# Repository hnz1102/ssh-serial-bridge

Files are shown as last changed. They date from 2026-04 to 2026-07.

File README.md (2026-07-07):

<div align="center">
  <h1><code>SSH Serial Bridge</code></h1>
  <p>
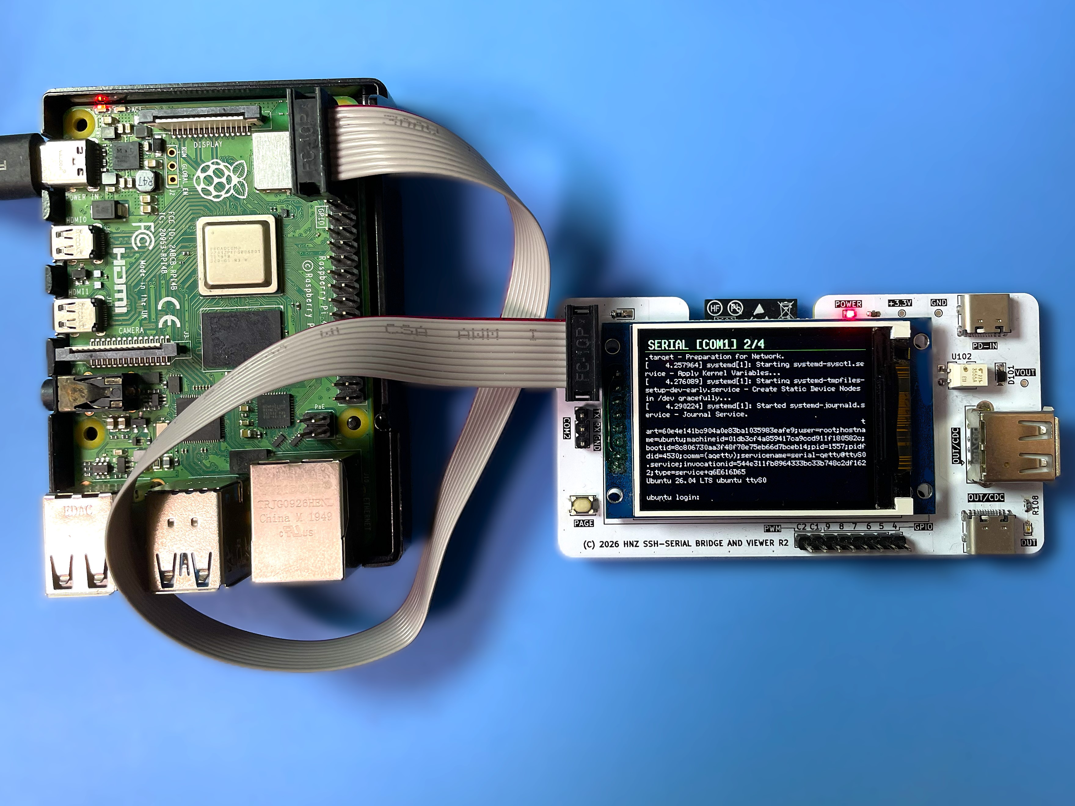
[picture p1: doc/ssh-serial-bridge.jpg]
    
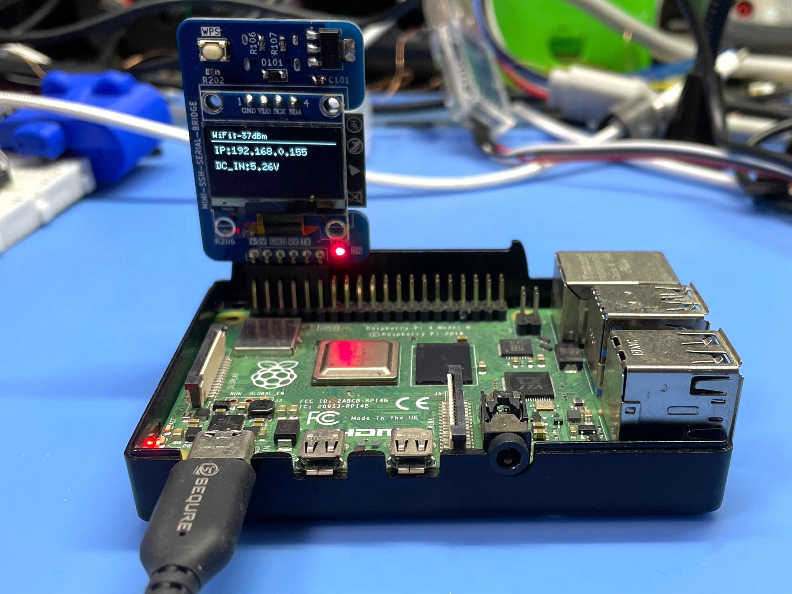
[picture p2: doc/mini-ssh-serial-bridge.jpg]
    
  </p>
</div>

# ssh-serial-bridge - SSH-to-Serial Bridge for Raspberry Pi, USB CDC and UART

Firmware for the ESP32-S3 that bridges an SSH connection (over Wi-Fi) to UART
and USB CDC serial ports.  Written in Rust (esp-idf-hal / esp-idf-svc) with a
C component (wolfSSH) for the SSH server.

## Features

| Feature | Description |
|---|---|
| SSH server | Port 22, username/password authentication via wolfSSH, multiple concurrent sessions (including shared sessions on the same serial port) |
| Serial ports | COM1 / COM2 (UART) and USB CDC (USB Host) — up to 4 ports (`usb0`–`usb3`) |
| Web UI | Browser-based configuration, terminal, and GPIO control |
| WebSocket terminal | Built-in xterm.js; access serial data from the browser at `/terminal` |
| WPS support | Wi-Fi Protected Setup (PBC mode) — configure Wi-Fi via button or Web UI |
| GPIO / PWM | Digital output (ON/OFF) on GPIO 4–9, 12 ; PWM output on GPIO 10–11 |
| SPI display | Optional ST7789V (320×240) display showing incoming serial data |
| UDP Syslog | RFC 5424 remote logging over UDP |
| NTP | Time synchronisation on boot; up to 4 servers configurable via Web UI |
| NVS settings | Persistent configuration stored in NVS; editable via Web UI at runtime |

---

## Architecture

```
SSH client ──[TCP:22]──► ssh_bridge.c (wolfSSH)
                               │
        per-session ring buffers (PSRAM)
                               │
Rust usb_host.rs ◄─────────────┘
 ├── COM1 (UART1)
 ├── COM2 (UART2)
 └── USB CDC (USB Host: PL2303 / FTDI / etc.)

Browser ──[HTTP/WS]──► httpserver.rs
 ├── /terminal  (xterm.js + WebSocket /ws/serial)
 ├── /          (configuration page)
 └── /gpio      (GPIO/PWM control page)
```

---

## Directory Layout

```
ssh-serial-bridge/
├── src/
│   ├── main.rs           # Entry point, peripheral initialisation
│   ├── usb_host.rs       # USB Host (PL2303 etc.) + UART + SSH bridge control
│   ├── httpserver.rs     # HTTP/WebSocket server, NVS config management
│   ├── wifi.rs           # Wi-Fi STA connection (DHCP / static IP)
│   ├── syslogger.rs      # UDP Syslog logger (RFC 5424)
│   ├── serial_display.rs # ST7789V SPI display rendering
│   ├── gpio_ctrl.rs      # Shared GPIO / PWM state
│   ├── btn_ctrl.rs       # GPIO0 button (short press: page cycle; long press: factory reset)
│   └── boot_log.rs       # NVS boot counter and rolling reset-reason log (last 10 entries)
├── components/
│   ├── ssh_bridge/       # SSH server C component (wolfSSH wrapper)
│   ├── wolfssh/          # wolfSSH (github.com/wolfSSL/wolfssh, commit 157cb01f)
│   └── wolfssl/          # wolfSSL/wolfCrypt (github.com/wolfSSL/wolfssl, commit b7e7e755)
├── static/               # Embedded static files (xterm.js / css / fit addon)
├── cfg.toml              # Build-time default configuration (gitignored — contains credentials)
├── cfg.toml.<board>      # Board-specific templates (e.g. ssh-bridge-board / xiao-esp32s3)
├── sdkconfig.defaults    # ESP-IDF build settings
├── partitions.csv        # Flash partition table
├── build-flash-images.sh # Build merged flash + app-only OTA images per board
├── setup_components.sh   # Initial setup script for components/
└── setup_env.sh          # One-shot environment setup (Rust, espup, udev)
```

---

## Pin Assignment

### UART Serial

| Port | Signal | Default GPIO | XIAO-ESP32S3 |
|---|---|---|---|
| COM1 | TX | 17 | 43 |
| COM1 | RX | 18 | 44 |
| COM2 | TX | 19 (41) | — |
| COM2 | RX | 20 (42) | — |

### GPIO / PWM Output

| GPIO | Function |
|---|---|
| 4–9, 12 | Digital output ON/OFF |
| 10–11 | PWM output (LEDC, 1 kHz, 14-bit) |

### SPI Display (ST7789V)

| Signal | GPIO |
|---|---|
| SCLK | 48 |
| MOSI | 45 |
| CS | 40 |
| DC | 39 |
| RST | 38 |

### Button

| GPIO | Function |
|---|---|
| 0 (BOOT) | Short press (<3 s): Cycle display page / Medium press (3–10 s): Toggle DC OUT (GPIO12) / Long press (≥10 s): NVS factory reset |
**Factory Reset Display Indicators:**
- **6–10 seconds** (button held): Display shows "FACTORY RESET" with countdown "Resetting to defaults in X seconds..."
- **10 seconds** (trigger): Display shows "FACTORY RESET" / "Erasing NVS... Please wait..." and device reboots
---

## Configuration

### Board-specific cfg.toml (build-time defaults)

Before building, choose a board config and copy it to `cfg.toml`.

- `ssh-bridge-board`: Board with a 2.0-inch TFT display for serial data output
- `mini-ssh-bridge-board`: Small-display board using SSD1306
- `xiao-esp32s3`: XIAO ESP32S3 board

```bash
# 2.0-inch TFT display board
cp cfg.toml.ssh-bridge-board cfg.toml

# SSD1306 mini display board
cp cfg.toml.mini-ssh-bridge-board cfg.toml

# XIAO ESP32S3 board
cp cfg.toml.xiao-esp32s3 cfg.toml
```

After copying, edit `cfg.toml` for your environment (Wi-Fi credentials, IP, etc.) if needed.

```toml
[ssh-serial-bridge]
wifi_ssid      = "your-ssid"
wifi_psk       = "your-password"
ip_mode        = "dhcp"           # "dhcp" or "static"
ip_address     = "192.168.2.200"
subnet_mask    = "255.255.255.0"
gateway        = "192.168.2.1"
dns            = "1.1.1.1"

syslog_server    = "192.168.2.140:514"
syslog_enable    = "false"
syslog_host_name = "esp32s3"
syslog_app_name  = "ssh-bridge"

ssh_user     = "admin"
ssh_password = "sshpass"

com1_tx_pin = "17"    # XIAO-ESP32S3: 43
com1_rx_pin = "18"    # XIAO-ESP32S3: 44
com1_baud   = "115200"
com2_tx_pin = "41"
com2_rx_pin = "42"
com2_baud   = "115200"

cdc_enable = "false"
cdc_baud   = "115200"

# CDC retry settings (for slow-initializing devices like Raspberry Pi USB Gadget)
cdc_retry_enable   = "true"    # Automatically retry CDC-ACM init until device is ready
cdc_retry_interval = "5"       # Seconds between retries (recommended: 5)

display_enable = "false"
display_port   = "com1"    # "com1" / "com2" / "usb0" / "usb1" / "usb2" / "usb3"

pwm_enable = "true"

# NTP servers (up to 4, in priority order)
ntp_server1 = "time.aws.com"
ntp_server2 = "time.google.com"
ntp_server3 = "time.cloudflare.com"
ntp_server4 = "ntp.nict.jp"

adc_conversion_factor = "74.47"　＃Factor to convert ADC reading to voltage (depends on voltage divider and reference voltage)
```

Values in `cfg.toml` are compiled into the firmware as defaults.  
After boot they can be overridden via the Web UI or direct NVS writes; NVS values take priority.

---

## Wi-Fi Setup with WPS

**WPS (Wi-Fi Protected Setup)** allows you to connect to a Wi-Fi network without manually entering the SSID and password. This device supports **WPS Push Button Configuration (PBC)** mode.

### Method 1: Using cfg.toml and Factory Reset (Recommended for initial setup)

If you don't have Wi-Fi credentials yet or want to reconfigure via WPS without Web UI access:

1. **Edit `cfg.toml` before building** (or rebuild the firmware):
   ```toml
   wifi_ssid      = ""           # Set to empty string
   wps_enable     = "true"       # Enable WPS mode on boot
   ```

2. **Flash the firmware** to the device

3. On boot, the device will automatically enter WPS mode and wait for you to **press the WPS button on your Wi-Fi router** (timeout: 2 minutes)

4. Upon successful WPS connection, the credentials are saved to NVS and the device reboots

**Alternative: Trigger WPS via Factory Reset**

If the device is already running with Wi-Fi configured but you want to switch to WPS:

1. **Edit `cfg.toml`** to set `wps_enable = "true"` and `wifi_ssid = ""`
2. **Rebuild and flash** the firmware
3. **Perform a Factory Reset**: Press and hold the BOOT button (GPIO 0) for **≥10 seconds**
4. The device will erase NVS, restore `cfg.toml` defaults, and reboot into WPS mode
5. **Press the WPS button on your Wi-Fi router** within 2 minutes

> **Note**: Web UI is not accessible until Wi-Fi is connected, so this method is essential for initial setup or when you lose Wi-Fi access.

---

### Method 2: Using the Web UI (when already connected to Wi-Fi)

1. Navigate to the configuration page at `http://<device_ip>/`
2. Find the **WPS** section
3. Click the **"Start WPS"** button
4. **Press the WPS button on your Wi-Fi router** within 2 minutes
5. The device will automatically receive and save the Wi-Fi credentials and reboot

### WPS Status Indicators

When WPS is active:
- **Display (if enabled)**: Shows "WPS MODE" with countdown timer (120 seconds)
  - "Press WPS button on your router within 120 seconds"
  - Countdown updates every 10 seconds
  - On success: "WPS SUCCESS" → "Connecting to {SSID}" → "CONNECTED"
- **Syslog (if enabled)**: Logs WPS start, success, or failure events
- **Web UI**: Shows WPS status during the connection process

### WPS Fallback

If WPS fails or times out, the device will revert to the previously configured Wi-Fi credentials (from `cfg.toml` or NVS).

### Notes

- WPS PBC mode is the only supported WPS method (PIN mode is not supported)
- After successful WPS configuration, the new credentials are saved to NVS and persist across reboots
- You can still manually configure Wi-Fi credentials via `cfg.toml` or the Web UI if WPS is not available on your router

---

## Environment Setup

Run `setup_env.sh` **once** on a fresh Ubuntu / Debian machine (or WSL2) before
building.  The script performs all steps below automatically.

```bash
bash setup_env.sh
```

After the script finishes, open a new terminal (or reload your shell config) so
the environment variables take effect:

```bash
source "$HOME/.cargo/env"
source ~/export-esp.sh
```

### What the script does

| Step | Action |
|---|---|
| 1 | Install system packages via `apt` |
| 2 | Install Rust toolchain via `rustup` (skipped if already present) |
| 3 | Install `ldproxy`, `espup`, `cargo-espflash` via Cargo |
| 4 | Install & update the ESP32-S3 Xtensa toolchain via `espup` |
| 5 | Source `~/export-esp.sh` (generated by `espup`) |
| 6 | Add udev rule for ESP32 USB device (`303a:1001`) and reload rules |

> If you prefer to run the steps manually, expand each step below.

<details>
<summary>Manual setup steps</summary>

```bash
# 1. System packages
sudo apt update && sudo apt -y install \
    git python3 python3-pip gcc build-essential curl \
    pkg-config libudev-dev libtinfo5 clang libclang-dev \
    llvm-dev udev libssl-dev python3.10-venv

# 2. Rust
curl --proto '=https' --tlsv1.2 -sSf https://sh.rustup.rs | sh
# Select option 1 (default install), then:
source "$HOME/.cargo/env"

# 3. Cargo tools
cargo install ldproxy
cargo install espup
cargo install cargo-espflash

# 4. ESP32-S3 toolchain
espup install
espup update

# 5. Activate ESP environment (add to ~/.bashrc / ~/.zshrc for persistence)
. ~/export-esp.sh

# 6. udev rules
sudo sh -c 'echo "SUBSYSTEMS==\"usb\", ATTRS{idVendor}==\"303a\", ATTRS{idProduct}==\"1001\", MODE=\"0666\"" > /etc/udev/rules.d/99-esp32.rules'
sudo udevadm control --reload-rules
sudo udevadm trigger
```

</details>

---

## Build and Flash

### Prerequisites

- Rust toolchain: `esp` channel (selected automatically via `rust-toolchain.toml`)
- [espup](https://github.com/esp-rs/espup) — ESP32-S3 Xtensa toolchain
- [espflash](https://github.com/esp-rs/espflash)

### Initial component setup

Run once after cloning, or after a clean wipe of `components/`:

```bash
cd esp32-s3/ssh-serial-bridge
bash setup_components.sh
```

This clones wolfssh and wolfssl at the verified commits and places the
ESP-IDF-specific `CMakeLists.txt` and `include/user_settings.h` on top.

### Build

```bash
cargo build --release
```

### Flash and monitor

```bash
espflash flash --release --monitor
```

### Creating a complete flash binary image

To create a single binary file that includes all partitions (bootloader,
partition table, data partitions, and the currently built app image) for
distribution or web-based flashing:

```bash
cargo espflash save-image --release --merge --chip esp32s3 complete_flash.bin
```

This creates a complete 8 MB flash image starting from offset 0x0.

### Creating board images for both USB flashing and OTA

The helper script builds all board configs and produces both image types:

- `flash_images/flash_<board>.bin` (merged full-flash image, write at `0x0`)
- `flash_images/app_<board>.bin` (app-only image for `ssh ... update` OTA)

```bash
bash build-flash-images.sh
```

**Important**: When flashing this image, always write it to **offset 0x0**, not 0x9000. Writing to 0x9000 will result in a boot failure with "invalid header: 0xffffffff" error.

#### Flash the complete binary

```bash
# Using esptool.py
esptool.py --chip esp32s3 --port /dev/ttyUSB0 write_flash 0x0 complete_flash.bin

# Using espflash
espflash write-bin 0x0 complete_flash.bin
```

#### Web-based flashing (no command line required)

You can also flash the binary via a web browser using the ESP Web Flasher:

1. Open [https://thelastoutpostworkshop.github.io/ESPConnect/](https://thelastoutpostworkshop.github.io/ESPConnect/) in Chrome, Edge, or Opera (Web Serial API required)
2. Click **"Connect"** and select your ESP32-S3 device from the serial port list
3. Click **"Choose File"** and select `complete_flash.bin`
4. Set the flash address to **`0x0`** (very important!)
5. Click **"Program"** to start flashing
6. Wait for the process to complete and click **"Reset Device"**

This method is ideal for:
- Users without command-line tools installed
- Quick firmware updates without installing the Rust/ESP toolchain
- Distribution of pre-built binaries

### Flash layout

| Partition | Offset  | Size |
|---|---|---|
| nvs | 0x9000  | 24 KB  |
| otadata | 0xF000  | 8 KB |
| phy_init | 0x11000 | 4 KB |
| ota_0 (app) | 0x20000 | 4032 KB |
| ota_1 (app) | 0x410000 | 4032 KB |

Flash: 8 MB, DIO mode, 40 MHz.

---

## Web UI Endpoints

### Web UI Snapshots

<div align="center">
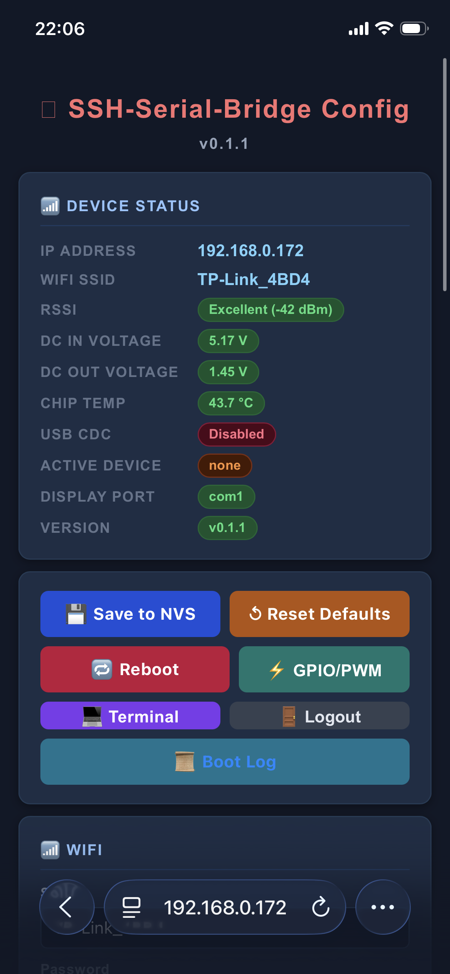
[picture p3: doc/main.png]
Web UI main configuration page
  
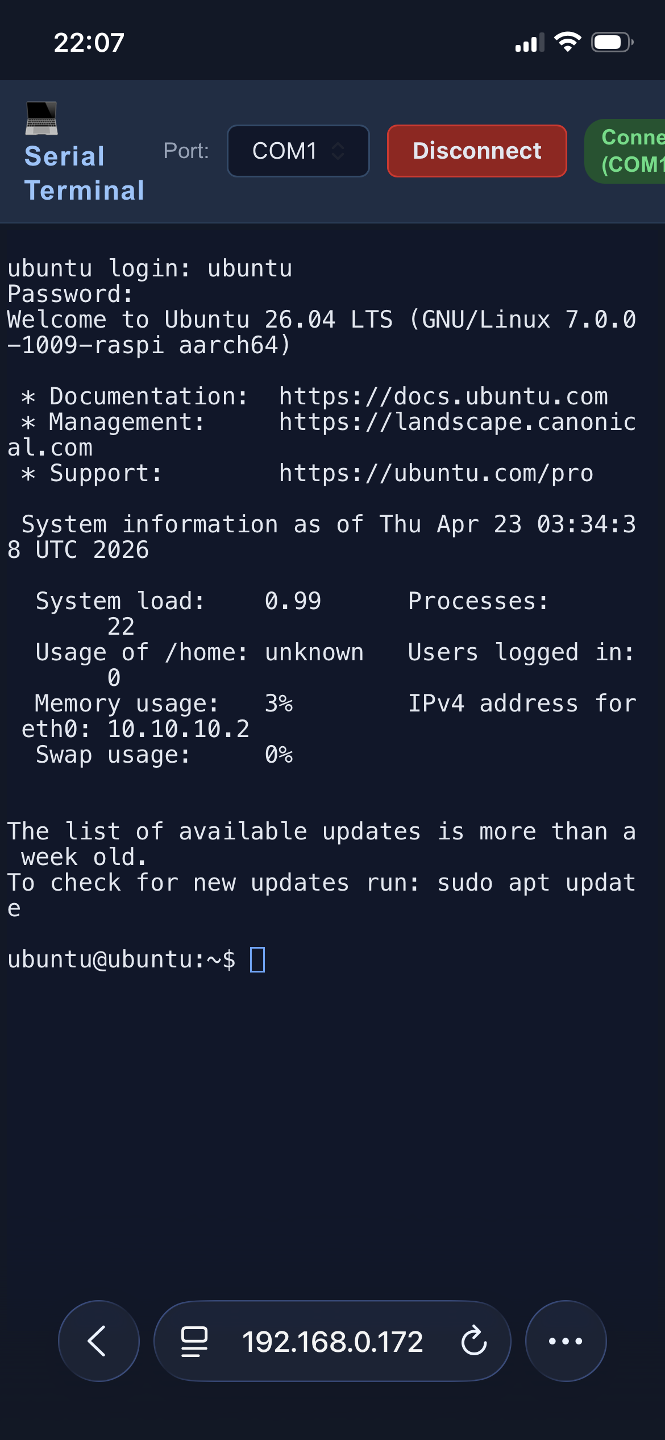
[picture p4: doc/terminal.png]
Web UI terminal page
  
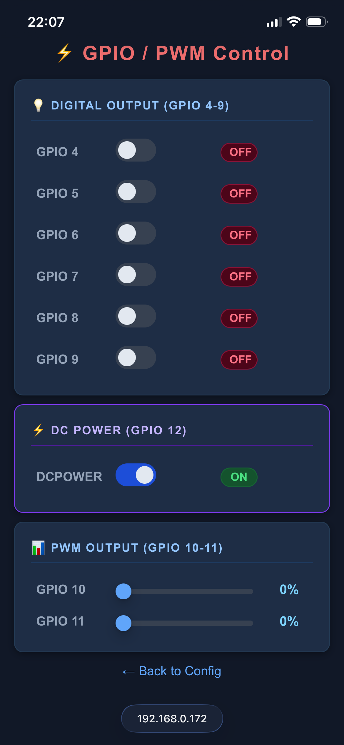
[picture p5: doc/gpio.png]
Web UI GPIO control page
  
</div>

| URL | Method | Description |
|-----|---|---|
| `/login` | GET / POST | Login |
| `/logout` | GET | Logout |
| `/` | GET | Configuration page (auth required) |
| `/gpio` | GET | GPIO / PWM control page (auth required) |
| `/terminal` | GET | WebSocket serial terminal (auth required) |
| `/ws/serial` | WS | Bidirectional serial bridge |
| `/api/config` | POST | Save configuration to NVS |
| `/api/status` | GET | Device / Wi-Fi / USB status (JSON) |
| `/api/reset` | POST | Erase NVS and restore cfg.toml defaults |
| `/api/reboot` | POST | Reboot the device |
| `/api/gpio` | POST | Set one digital output ON/OFF |
| `/api/pwm` | POST | Set PWM duty cycle (0–100 %) |
| `/api/gpio_state` | GET | Current GPIO / PWM state (JSON) |
| `/api/boot_log` | GET | Boot history with reset reasons from NVS (JSON) |

---

## SSH Connection

### Authentication

| Item | Detail |
|---|---|
| Port | 22 (TCP) |
| Auth method | Password only (public-key authentication is not supported) |
| Username | Any string is accepted — only the password is checked |
| Password | Set via `ssh_password` in `cfg.toml` or Web UI (default: `esp32`) |
| Concurrent sessions | Up to 6 total SSH sessions (including command sessions) |
| Per-device console sharing | Up to 4 concurrent console sessions on the same target (`usb0`-`usb3`, `com1`, `com2`) |

> **Security note:** Change the default password before deploying the device
> on a shared network.

---

### Commands

The SSH server dispatches on the command passed after the host.  
If no command is given, a usage summary is printed and the connection closes.

#### 1. Serial console bridge

Connects the SSH session as a transparent terminal to a serial port.

```bash
ssh -tt <user>@<device_ip> console (usb0|usb1|usb2|usb3|com1|com2)
```

| Argument | Description |
|---|---|
| `usb0` | First USB CDC device (plug order; alias: `usb`) |
| `usb1` | Second USB CDC device |
| `usb2` | Third USB CDC device |
| `usb3` | Fourth USB CDC device |
| `com1` | UART1 (pins configured by `com1_tx_pin` / `com1_rx_pin`) |
| `com2` | UART2 (pins configured by `com2_tx_pin` / `com2_rx_pin`) |

- The `-tt` flag forces pseudo-TTY allocation, which is required for correct
  terminal behaviour.
- A welcome banner is printed on connect:
  ```
  Connected to ESP32-S3 SSH-Serial-Bridge v0.1.1 [com1].
  Disconnect: Enter then ~.
  ```
- The same serial target can be shared by multiple SSH clients.  When another
  session is already connected to that target, the banner also shows:
  ```
  Note: N other session(s) are also connected to this device — input/output is shared.
  ```
- Shared-session behaviour on the same target:
  - RX from device is broadcast to all connected SSH sessions on that target.
  - TX from each SSH session is sent to the same physical serial line, so input
    from multiple users can interleave.
- Capacity limits:
  - Max 4 console sessions per target (`com1`, `com2`, `usb0`-`usb3`).
  - Max 6 total SSH sessions across the system.
- If a target already has 4 console sessions, new attempts are rejected with:
  ```
  Error: too many sessions already connected to this device (max 4).
  ```
- Serial data received before the first keystroke from the SSH client is
  discarded to prevent stale output flooding the terminal on login.
- Disconnect with the standard OpenSSH escape sequence: press **Enter**, then
  type **`~.`**

**Examples:**

```bash
# Connect to the first USB CDC device
ssh -tt admin@192.168.2.200 console usb0

# Connect to the second USB CDC device
ssh -tt admin@192.168.2.200 console usb1

# Connect to COM1 (UART1)
ssh -tt admin@192.168.2.200 console com1

# Connect to COM2 (UART2)
ssh -tt admin@192.168.2.200 console com2
```

---

#### 2. GPIO digital output control

Controls GPIO4–GPIO9 output pins (mapped as power outlets 1–6).

```bash
ssh <user>@<device_ip> power <1-6> (on|off)
```

| Argument | Description |
|---|---|
| `1`–`6`  | Outlet number: 1 = GPIO4, 2 = GPIO5, … 6 = GPIO9 |
| `on` | Set output HIGH |
| `off` | Set output LOW  |

**Examples:**

```bash
ssh admin@192.168.2.200 power 1 on    # GPIO4 → HIGH
ssh admin@192.168.2.200 power 3 off   # GPIO6 → LOW
```

---

#### 3. DC Power output control (GPIO12)

Controls the dedicated DC Power output on GPIO12.

```bash
ssh <user>@<device_ip> dcpower (on|off)
```

**Examples:**

```bash
ssh admin@192.168.2.200 dcpower on
ssh admin@192.168.2.200 dcpower off
```

---

#### 4. DC Power power-cycle (GPIO12)

Turns the DC Power output off, waits briefly, then turns it back on — in a single SSH call.

```bash
ssh <user>@<device_ip> powercycle
```

**Example:**

```bash
ssh admin@192.168.2.200 powercycle
```

---

#### 5. PWM duty cycle control

Sets the PWM duty cycle on GPIO10 or GPIO11 (LEDC, 1 kHz, 14-bit).

```bash
ssh <user>@<device_ip> pwm <1|2> <0-100>
```

| Argument | Description |
|---|---|
| `1` | Channel 1 — GPIO10 |
| `2` | Channel 2 — GPIO11 |
| `0`–`100`| Duty cycle in percent |

**Examples:**

```bash
ssh admin@192.168.2.200 pwm 1 50    # GPIO10 → 50 %
ssh admin@192.168.2.200 pwm 2 0     # GPIO11 → off
ssh admin@192.168.2.200 pwm 1 100   # GPIO10 → full on
```

---

#### 6. Reboot the device

Reboots the ESP32-S3 (equivalent to a power-on reset).

```bash
ssh <user>@<device_ip> reboot
```

**Example:**

```bash
ssh admin@192.168.2.200 reboot
```

---

#### 7. OTA firmware update

Streams a new app image over SSH directly into the inactive OTA partition, then
reboots into it. No filesystem, SCP, or SFTP support is required — the exec
channel's stdin is piped straight into flash.

```bash
ssh <user>@<device_ip> update < firmware.bin
```

**Example:**

```bash
cat flash_images/app_ssh-bridge-board.bin | ssh admin@192.168.2.200 update
```

**Important:**

- Use the **app-only** image (`flash_images/app_<board>.bin`, produced by
  `build-flash-images.sh`), **not** the merged full-flash image
  (`flash_images/flash_<board>.bin`). The merged image includes the
  bootloader and partition table baked in at offset 0 and will corrupt the
  OTA partition if written this way.
- The device has two OTA app slots (`ota_0`/`ota_1`). The update is written to
  whichever slot isn't currently running, so the previous firmware is left
  untouched until the new image is fully received and verified.
- **Rollback safety:** the new image boots in a "pending verify" state. Once
  the SSH bridge starts successfully it is marked valid automatically. If the
  new firmware crashes or fails to boot before that point, the bootloader
  automatically reverts to the previous working firmware on the next reset.
- This requires the partition table to include `ota_0`/`ota_1`/`otadata`
  (see `partitions.csv`). Boards flashed with an older single-partition image
  must be reflashed once via USB/serial (`cargo espflash flash` or the merged
  `flash_<board>.bin` image) before OTA updates over SSH will work.

---

### Usage summary (printed on unknown command)

```
ESP32-S3 SSH-Serial-Bridge
Usage:
  ssh -tt admin@host console (usb0|usb1|usb2|usb3|com1|com2)  -- Serial console bridge
  ssh    admin@host power   (1-6) (on|off)    -- GPIO4-9 output control
  ssh    admin@host dcpower (on|off)          -- DC Power output (GPIO12)
  ssh    admin@host powercycle                -- DC Power off->on (GPIO12)
  ssh    admin@host pwm   (1|2) (0-100)       -- PWM GPIO10-11 duty %
  ssh    admin@host reboot                    -- Reboot the ESP32-S3
  ssh    admin@host update < firmware.bin      -- OTA firmware update
```

---

## Supported USB CDC Devices

The USB Host driver auto-detects the connected adapter by VID/PID and applies
the appropriate initialisation sequence.  The baud rate is set by `cdc_baud`
in `cfg.toml` (default: `115200`).

> **Note:** `cdc_enable` must be set to `"true"` in `cfg.toml` (or via Web UI)
> to activate the USB Host driver.  When disabled, `usb0`–`usb3` are
> unavailable as SSH console targets.

### Vendor-class adapters

| Chip | VID | PID(s) | Ports | Notes |
|---|-----|---|---|---|
| **PL2303** | `067B` | `2303`, `23A3`, `2304` | 1 | Prolific Technology |
| **CP210x** | `10C4` | `EA60`, `EA61`, `EA70` | 1 | Silicon Labs |
| **FT232R** | `0403` | `6001` | 1 | FTDI |
| **FT232H** | `0403` | `6014` | 1 | FTDI |
| **FT2232H/D** | `0403` | `6010` | 2 | FTDI — maps to `usb0` / `usb1` |
| **FT4232H** | `0403` | `6011` | 4 | FTDI — maps to `usb0`–`usb3` |

### Linux USB Gadget (Raspberry Pi)

This firmware supports **Raspberry Pi USB Gadget mode** for direct serial access over USB:

| Device | VID | PID | Module | Notes |
|---|-----|-----|---|---|
| **Raspberry Pi (g_cdc)** | `0525` | `a4a7` | `g_cdc` | CDC-ACM composite device (recommended) |

#### Raspberry Pi Configuration

To use your Raspberry Pi as a USB serial gadget with this ESP32-S3 bridge:

1. **Enable USB gadget mode** on your Raspberry Pi:
   ```bash
   # Add to /boot/config.txt (or /boot/firmware/config.txt on Ubuntu)
   dtoverlay=dwc2
   ```

2. **Load the g_cdc module** (recommended over g_serial):
   
   **Method A: Using cmdline.txt (Recommended)**
   ```bash
   # Edit /boot/cmdline.txt (or /boot/firmware/cmdline.txt on Ubuntu)
   # Add modules-load=dwc2,g_cdc to the kernel command line
   # Example:
   console=serial0,115200 ... modules-load=dwc2,g_cdc ...
   ```
   
   **Method B: Using /etc/modules**
   ```bash
   # Add to /etc/modules
   dwc2
   g_cdc
   ```

3. **Enable serial-getty service** (required for the CDC device to respond):
   ```bash
   sudo systemctl enable serial-getty@ttyGS0
   sudo systemctl start serial-getty@ttyGS0
   ```

4. **Reboot your Raspberry Pi**:
   ```bash
   sudo reboot
   ```

5. **Connect the Pi to the ESP32-S3 USB port** using a USB cable

> **Important:** Use `g_cdc` instead of `g_serial`. The `g_serial` module has compatibility issues with the ESP-IDF USB Host stack and may not work reliably. `g_cdc` provides better standards compliance and works seamlessly with this firmware.

After configuration, the Pi will appear as a CDC-ACM device and you can access its serial console via SSH to the ESP32-S3 bridge (target: `usb0`).

### Port mapping

Multi-port FTDI adapters expose multiple ports, mapped to SSH console targets
in channel order:

| SSH target | Description |
|---|---|
| `usb0` | Port 1 — all single-port adapters; FT2232 ch.A; FT4232 ch.A |
| `usb1` | Port 2 — FT2232 ch.B; FT4232 ch.B |
| `usb2` | Port 3 — FT4232 ch.C |
| `usb3` | Port 4 — FT4232 ch.D |

---

## Dependencies

| Component / Library | Version | License | Purpose |
|---|---|---|---|
| **ssh-serial-bridge** (this project) | 0.1.1 | MIT | Firmware (Rust) |
| **ssh_bridge** component | 0.1.1 | MIT | SSH server C wrapper |
| esp-idf-hal | 0.45.2 | MIT / Apache-2.0 | ESP32-S3 hardware abstraction |
| esp-idf-svc | 0.51 | MIT / Apache-2.0 | Wi-Fi, HTTP server, SNTP, etc. |
| **wolfSSH** | commit `157cb01f` | GPLv3 (or commercial) | SSH server protocol |
| **wolfSSL / wolfCrypt** | commit `b7e7e755` | GPLv3 (or commercial) | Cryptography library |
| mipidsi | 0.8.0 | MIT | ST7789V display driver |
| embedded-graphics | 0.8.1 | MIT | Display rendering |
| @xterm/xterm | 6.0.0 (bundled) | MIT | Browser WebSocket terminal |
| @xterm/addon-fit | 0.11.0 (bundled) | MIT | xterm.js terminal fit addon |

> **Note on wolfSSH / wolfSSL licensing:**  
> Both wolfSSH and wolfSSL are dual-licensed under **GPLv3** (open source) or a
> **commercial license** (for use in proprietary products).

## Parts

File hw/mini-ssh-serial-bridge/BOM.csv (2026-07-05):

Reference | Qty | Value | DNP | Exclude from BOM | Exclude from Board | Footprint | digikey
C101,C201,C202 | 3 | 0.1uF |  |  |  | Capacitor_SMD:C_0603_1608Metric | 311-1343-1-ND
C203 | 1 | 10uF |  |  |  | Capacitor_SMD:C_0805_2012Metric | 311-1355-1-ND
D101 | 1 | CUHS20F60 |  |  |  | Diode_SMD:D_PowerDI-123 | 264-CUHS20F60H3FCT-ND
D103 | 1 | LED RED |  |  |  | LED_SMD:LED_0603_1608Metric | 3147-B1931URO-20D000114U1930CT-ND
FB101 | 1 | MH2029-601Y |  |  |  | Inductor_SMD:L_0805_2012Metric | MH2029-601YCT-ND
J101 | 1 | USB4105-GF-A |  |  |  | tbctl:USB_C_5077CR-16-SMC2-BK-TR | 2073-USB4105-GF-ACT-ND
J102 | 1 | Conn_01x06 |  |  |  | Connector_PinHeader_2.54mm:PinHeader_1x06_P2.54mm_Vertical | S5442-ND
R105 | 1 | 330 |  |  |  | Resistor_SMD:R_0603_1608Metric | 13-RC0603JR-13330RLCT-ND
R106,R107 | 2 | 5K1 |  |  |  | Resistor_SMD:R_0603_1608Metric | 311-5.10KHRCT-ND
R201,R202 | 2 | 10K |  |  |  | Resistor_SMD:R_0603_1608Metric | 311-10.0KHRCT-ND
R204 | 1 | 47K 1% |  |  |  | Resistor_SMD:R_0603_1608Metric | 311-47.0KHRCT-ND
R206 | 1 | 4.7K 1% |  |  |  | Resistor_SMD:R_0603_1608Metric | 311-4.70KHRCT-ND
SW304 | 1 | 1 |  |  |  | tbctl:SW_SKRPACE010_4mm_3mm | P12298SCT-ND
U101 | 1 | SSD1306_DISPLAY |  |  |  | tbctl:OLED I2C DISPLAY | https://akizukidenshi.com/catalog/g/g112031/
U103 | 1 | AZ1117-CH3.3TRG1 |  |  |  | Package_TO_SOT_SMD:SOT-223-3_TabPin2 | AZ1117CH-3.3TRG1DICT-ND
U201 | 1 | ESP32-S3-WROOM-1-N16R8 |  |  |  | tbctl:ESP32-S3-WROOM-1_EXP | 1965-ESP32-S3-WROOM-1-N16R8CT-ND

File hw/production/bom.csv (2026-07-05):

Designator | Footprint | Quantity | Value | LCSC Part #
C101, C201, C202 | 0603 | 3 | 0.1uF
C203 | 0805 | 1 | 10uF
D101 | D_PowerDI-123 | 1 | CUHS20F60
D103 | 0603 | 1 | LED RED
D402 | 0603 | 1 | LED BLUE
FB101 | 0805 | 1 | MH2029-601Y
J1 | PinHeader_1x04_P2.54mm_Vertical | 1 | Conn_01x04
J101, J102 | USB_C_5077CR-16-SMC2-BK-TR | 2 | USB4105-GF-A
J104 | PinHeader_2x05_P2.54mm_Vertical | 1 | Conn_02x05_Odd_Even
J105 | USB_A_5075AR-04 | 1 | USB_A
J2 | PinHeader_1x10_P2.54mm_Vertical | 1 | Conn_01x10
R101 | 0603 | 1 | 150
R102, R204 | 0603 | 2 | 47K 1%
R103, R206 | 0603 | 2 | 4.7K 1%
R104, R109 | 0603 | 2 | 75K
R105 | 0603 | 1 | 330
R106, R107 | 0603 | 2 | 5K1
R108 | 0603 | 1 | 1K
R110, R111 | 0603 | 2 | 51K
R201, R202 | 0603 | 2 | 10K
SW304 | SW_SKRPACE010_4mm_3mm | 1 | 1
TP101 | TestPoint_Pad_D1.0mm | 1 | 3V3
TP102 | TestPoint_Pad_D1.0mm | 1 | GND
TP103 | TestPoint_Pad_D1.0mm | 1 | VBUS_OUT
U101 | ST7789V TFT SPI DISPLAY 320x240 GMT020-02-8P | 1 | ST7789V_TFT_DISPLAY_8P
U102 | DIP-4_W7.62mm | 1 | TLP3555A
U103 | SOT-223-3_TabPin2 | 1 | AZ1117-CH3.3TRG1
U201 | ESP32-S3-WROOM-1_EXP | 1 | ESP32-S3-WROOM-1-N16R8

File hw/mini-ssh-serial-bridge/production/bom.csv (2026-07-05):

Designator | Footprint | Quantity | Value | LCSC Part #
C101, C201, C202 | 0603 | 3 | 0.1uF
C203 | 0805 | 1 | 10uF
D101 | D_PowerDI-123 | 1 | CUHS20F60
D103 | 0603 | 1 | LED RED
FB101 | 0805 | 1 | MH2029-601Y
J101 | USB_C_5077CR-16-SMC2-BK-TR | 1 | USB4105-GF-A
J102 | PinHeader_1x06_P2.54mm_Vertical | 1 | Conn_01x06
R105 | 0603 | 1 | 330
R106, R107 | 0603 | 2 | 5K1
R201, R202 | 0603 | 2 | 10K
R204 | 0603 | 1 | 47K 1%
R206 | 0603 | 1 | 4.7K 1%
SW304 | SW_SKRPACE010_4mm_3mm | 1 | 1
U101 | OLED I2C DISPLAY | 1 | SSD1306_DISPLAY
U103 | SOT-223-3_TabPin2 | 1 | AZ1117-CH3.3TRG1
U201 | ESP32-S3-WROOM-1_EXP | 1 | ESP32-S3-WROOM-1-N16R8

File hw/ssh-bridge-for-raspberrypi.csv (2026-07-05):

Reference | Qty | Value | DNP | Exclude from BOM | Exclude from Board | Footprint | digikey
C101,C201,C202 | 3 | 0.1uF |  |  |  | Capacitor_SMD:C_0603_1608Metric | 311-1343-1-ND
C203 | 1 | 10uF |  |  |  | Capacitor_SMD:C_0805_2012Metric | 311-1355-1-ND
D101 | 1 | CUHS20F60 |  |  |  | Diode_SMD:D_PowerDI-123 | 264-CUHS20F60H3FCT-ND
D103 | 1 | LED RED |  |  |  | LED_SMD:LED_0603_1608Metric | 3147-B1931URO-20D000114U1930CT-ND
D402 | 1 | LED BLUE |  |  |  | LED_SMD:LED_0603_1608Metric | 3147-B1931NB--20C007614U1930CT-ND
FB101 | 1 | MH2029-601Y |  |  |  | Inductor_SMD:L_0805_2012Metric | MH2029-601YCT-ND
J1 | 1 | Conn_01x04 |  |  |  | Connector_PinHeader_2.54mm:PinHeader_1x04_P2.54mm_Vertical | 732-5317-ND
J2 | 1 | Conn_01x10 |  |  |  | Connector_PinHeader_2.54mm:PinHeader_1x10_P2.54mm_Vertical | 732-2670-ND
J101,J102 | 2 | USB4105-GF-A |  |  |  | Library:USB_C_5077CR-16-SMC2-BK-TR | 2073-USB4105-GF-ACT-ND
J104 | 1 | Conn_02x05_Odd_Even |  |  |  | Connector_PinHeader_2.54mm:PinHeader_2x05_P2.54mm_Vertical | 732-2672-ND
J105 | 1 | USB_A |  |  |  | Library:USB_A_5075AR-04 | ED2989-ND
R101 | 1 | 150 |  |  |  | Resistor_SMD:R_0603_1608Metric | 13-RC0603FR-13150RLCT-ND
R102,R204 | 2 | 47K 1% |  |  |  | Resistor_SMD:R_0603_1608Metric | 311-47.0KHRCT-ND
R103,R206 | 2 | 4.7K 1% |  |  |  | Resistor_SMD:R_0603_1608Metric | 311-4.70KHRCT-ND
R104,R109 | 2 | 75K |  |  |  | Resistor_SMD:R_0603_1608Metric | 311-75.0KHRCT-ND
R105 | 1 | 330 |  |  |  | Resistor_SMD:R_0603_1608Metric | 13-RC0603JR-13330RLCT-ND
R106,R107 | 2 | 5K1 |  |  |  | Resistor_SMD:R_0603_1608Metric | 311-5.10KHRCT-ND
R108 | 1 | 1K |  |  |  | Resistor_SMD:R_0603_1608Metric | 311-1.00KHRCT-ND
R110,R111 | 2 | 51K |  |  |  | Resistor_SMD:R_0603_1608Metric | 311-51.0KHRCT-ND
R201,R202 | 2 | 10K |  |  |  | Resistor_SMD:R_0603_1608Metric | 311-10.0KHRCT-ND
SW304 | 1 | 1 |  |  |  | Library:SW_SKRPACE010_4mm_3mm | P12298SCT-ND
TP101 | 1 | 3V3 |  |  |  | TestPoint:TestPoint_Pad_D1.0mm | -
TP102 | 1 | GND |  |  |  | TestPoint:TestPoint_Pad_D1.0mm | -
TP103 | 1 | VBUS_OUT |  |  |  | TestPoint:TestPoint_Pad_D1.0mm | -
U101 | 1 | ST7789V_TFT_DISPLAY_8P |  |  |  | Library:ST7789V TFT SPI DISPLAY 320x240 GMT020-02-8P
U102 | 1 | TLP3555A |  |  |  | Package_DIP:DIP-4_W7.62mm | TLP3555A(F-ND
U103 | 1 | AZ1117-CH3.3TRG1 |  |  |  | Package_TO_SOT_SMD:SOT-223-3_TabPin2 | AZ1117CH-3.3TRG1DICT-ND
U201 | 1 | ESP32-S3-WROOM-1-N16R8 |  |  |  | Library:ESP32-S3-WROOM-1_EXP | 1965-ESP32-S3-WROOM-1-N16R8CT-ND

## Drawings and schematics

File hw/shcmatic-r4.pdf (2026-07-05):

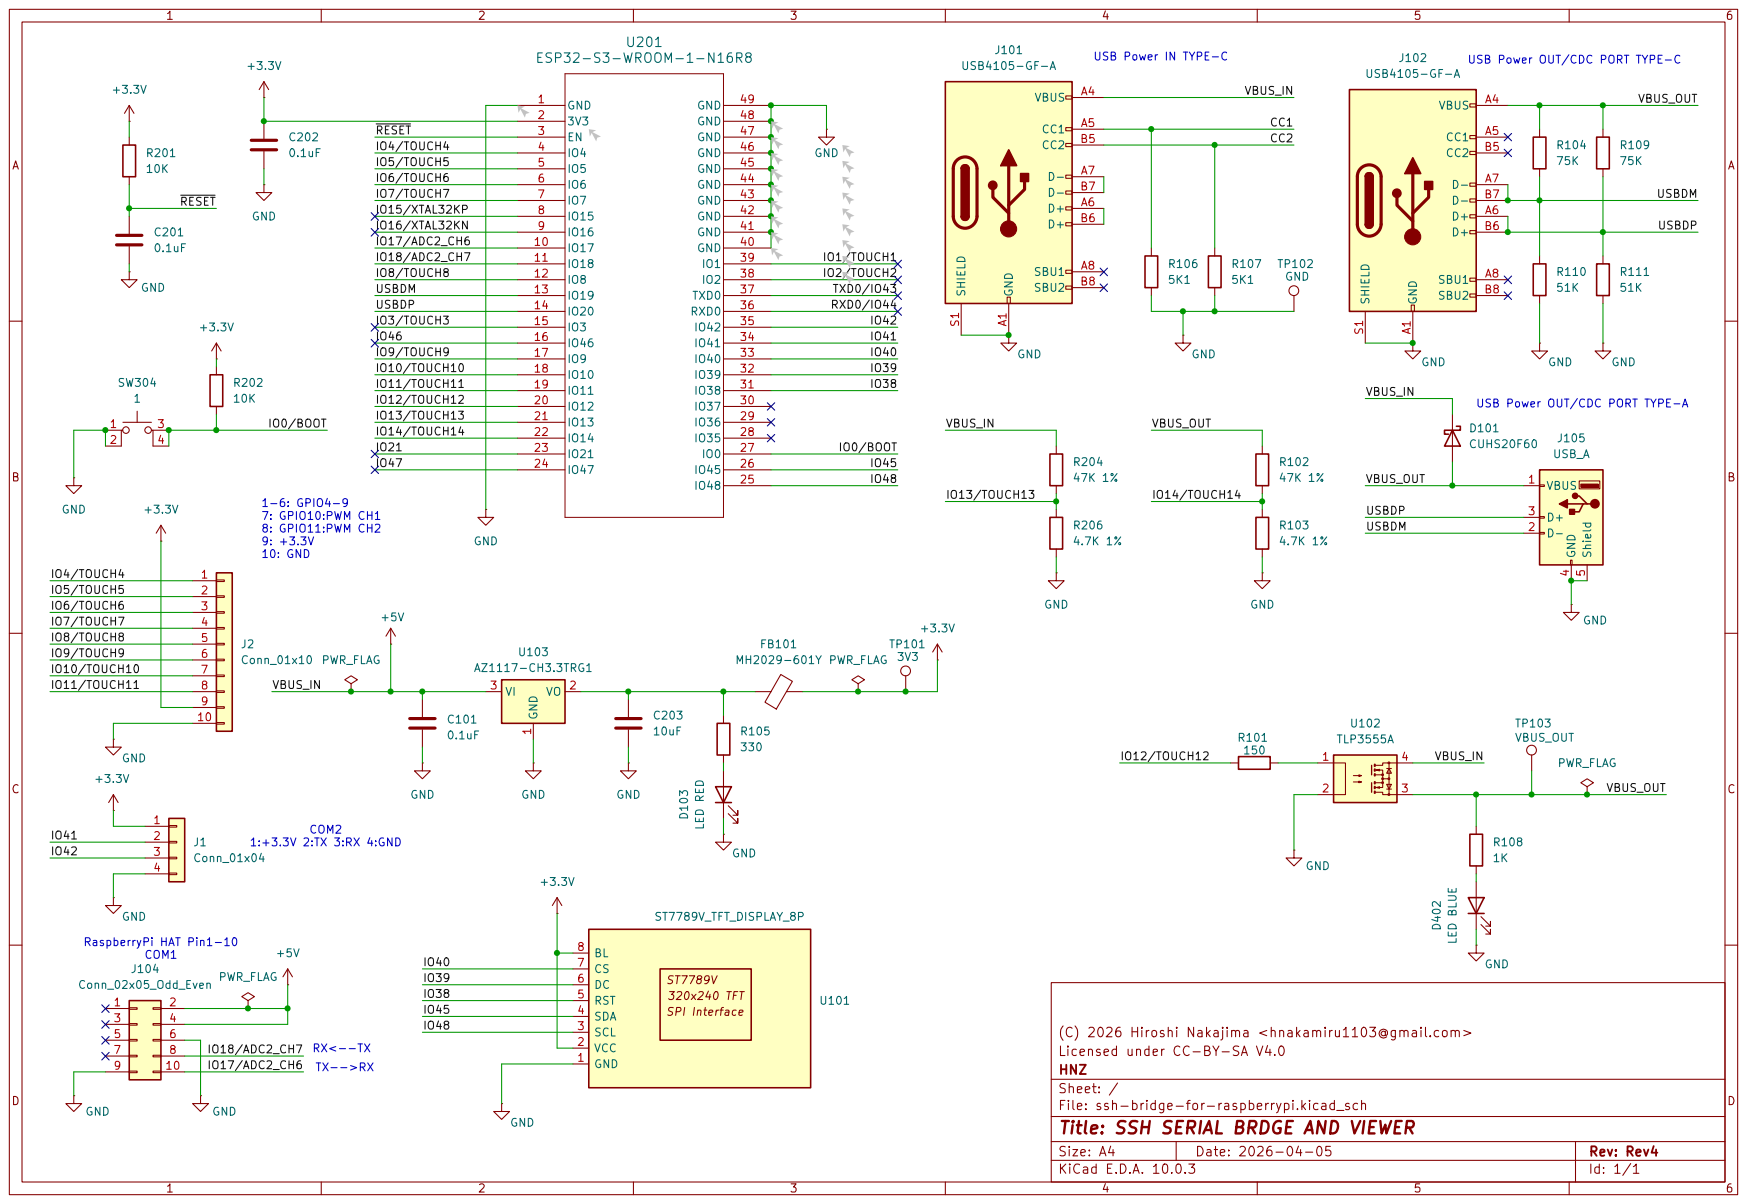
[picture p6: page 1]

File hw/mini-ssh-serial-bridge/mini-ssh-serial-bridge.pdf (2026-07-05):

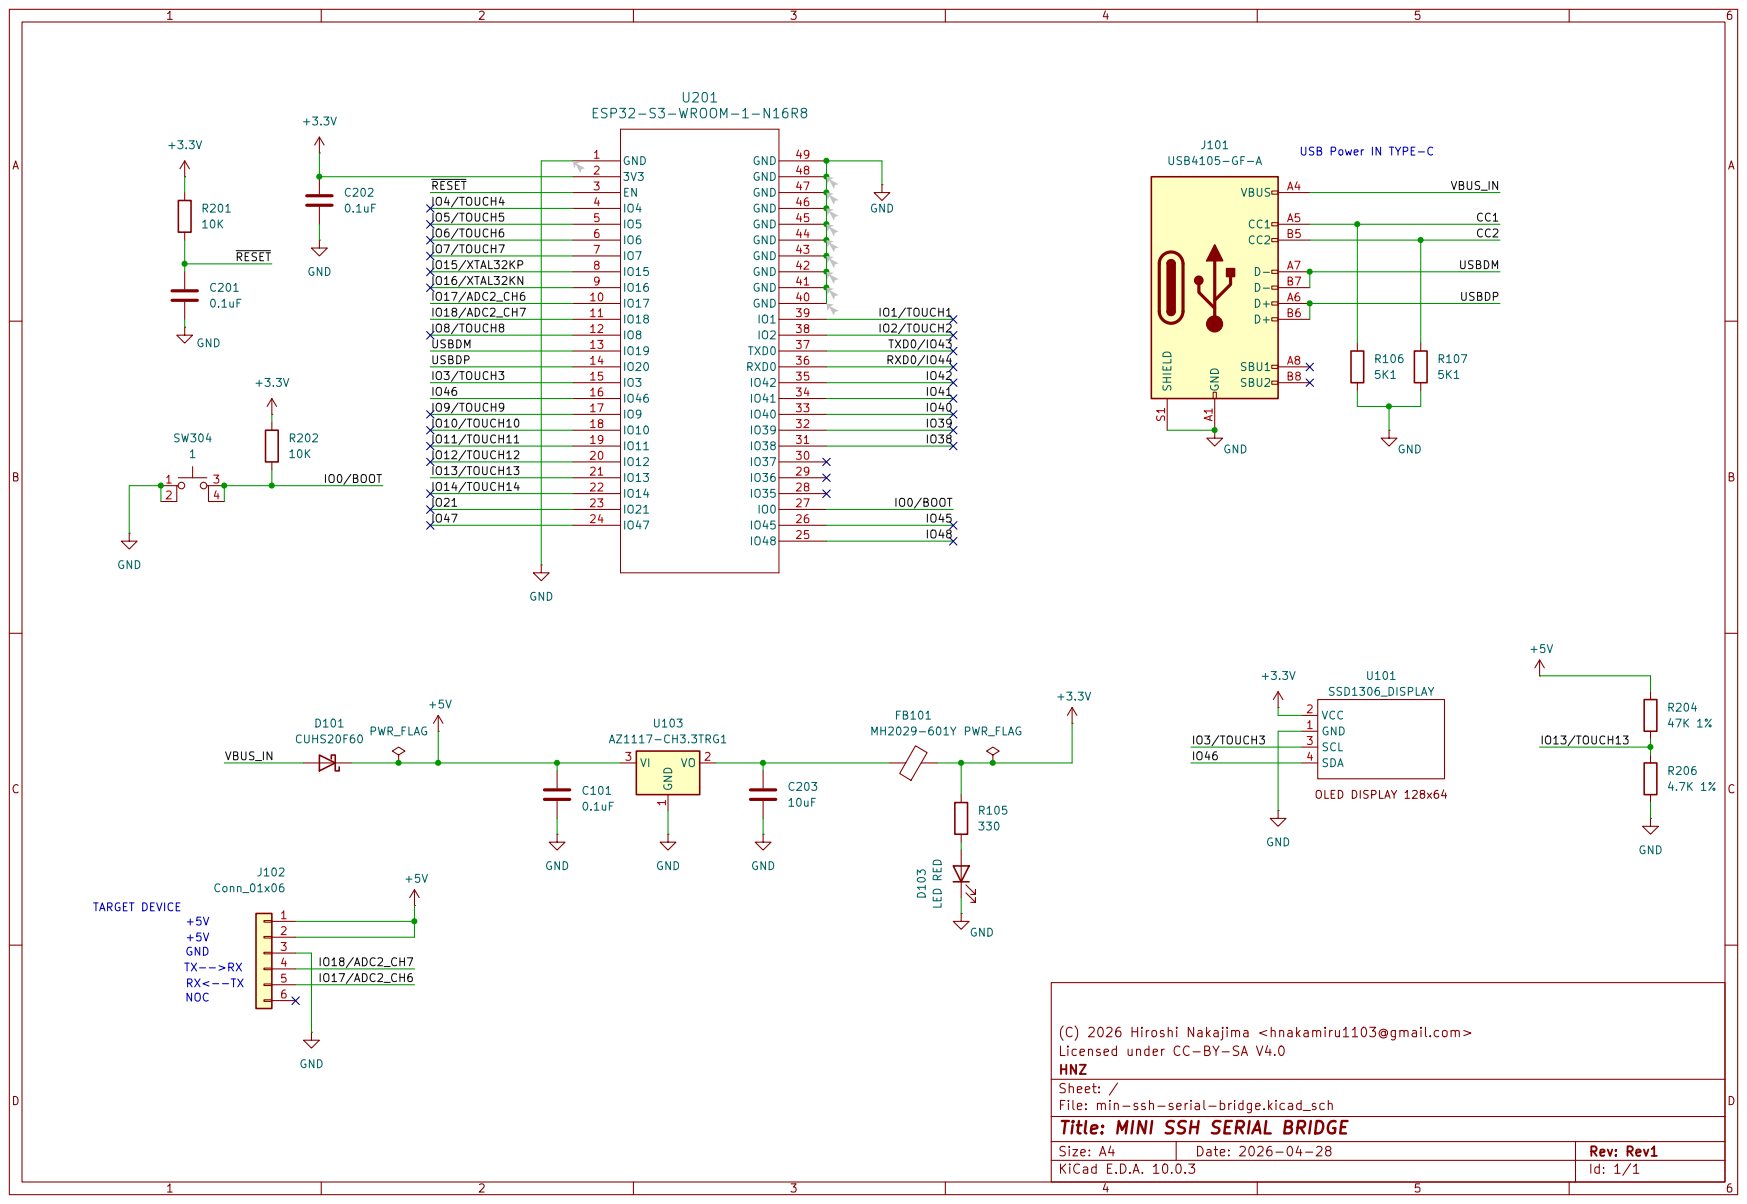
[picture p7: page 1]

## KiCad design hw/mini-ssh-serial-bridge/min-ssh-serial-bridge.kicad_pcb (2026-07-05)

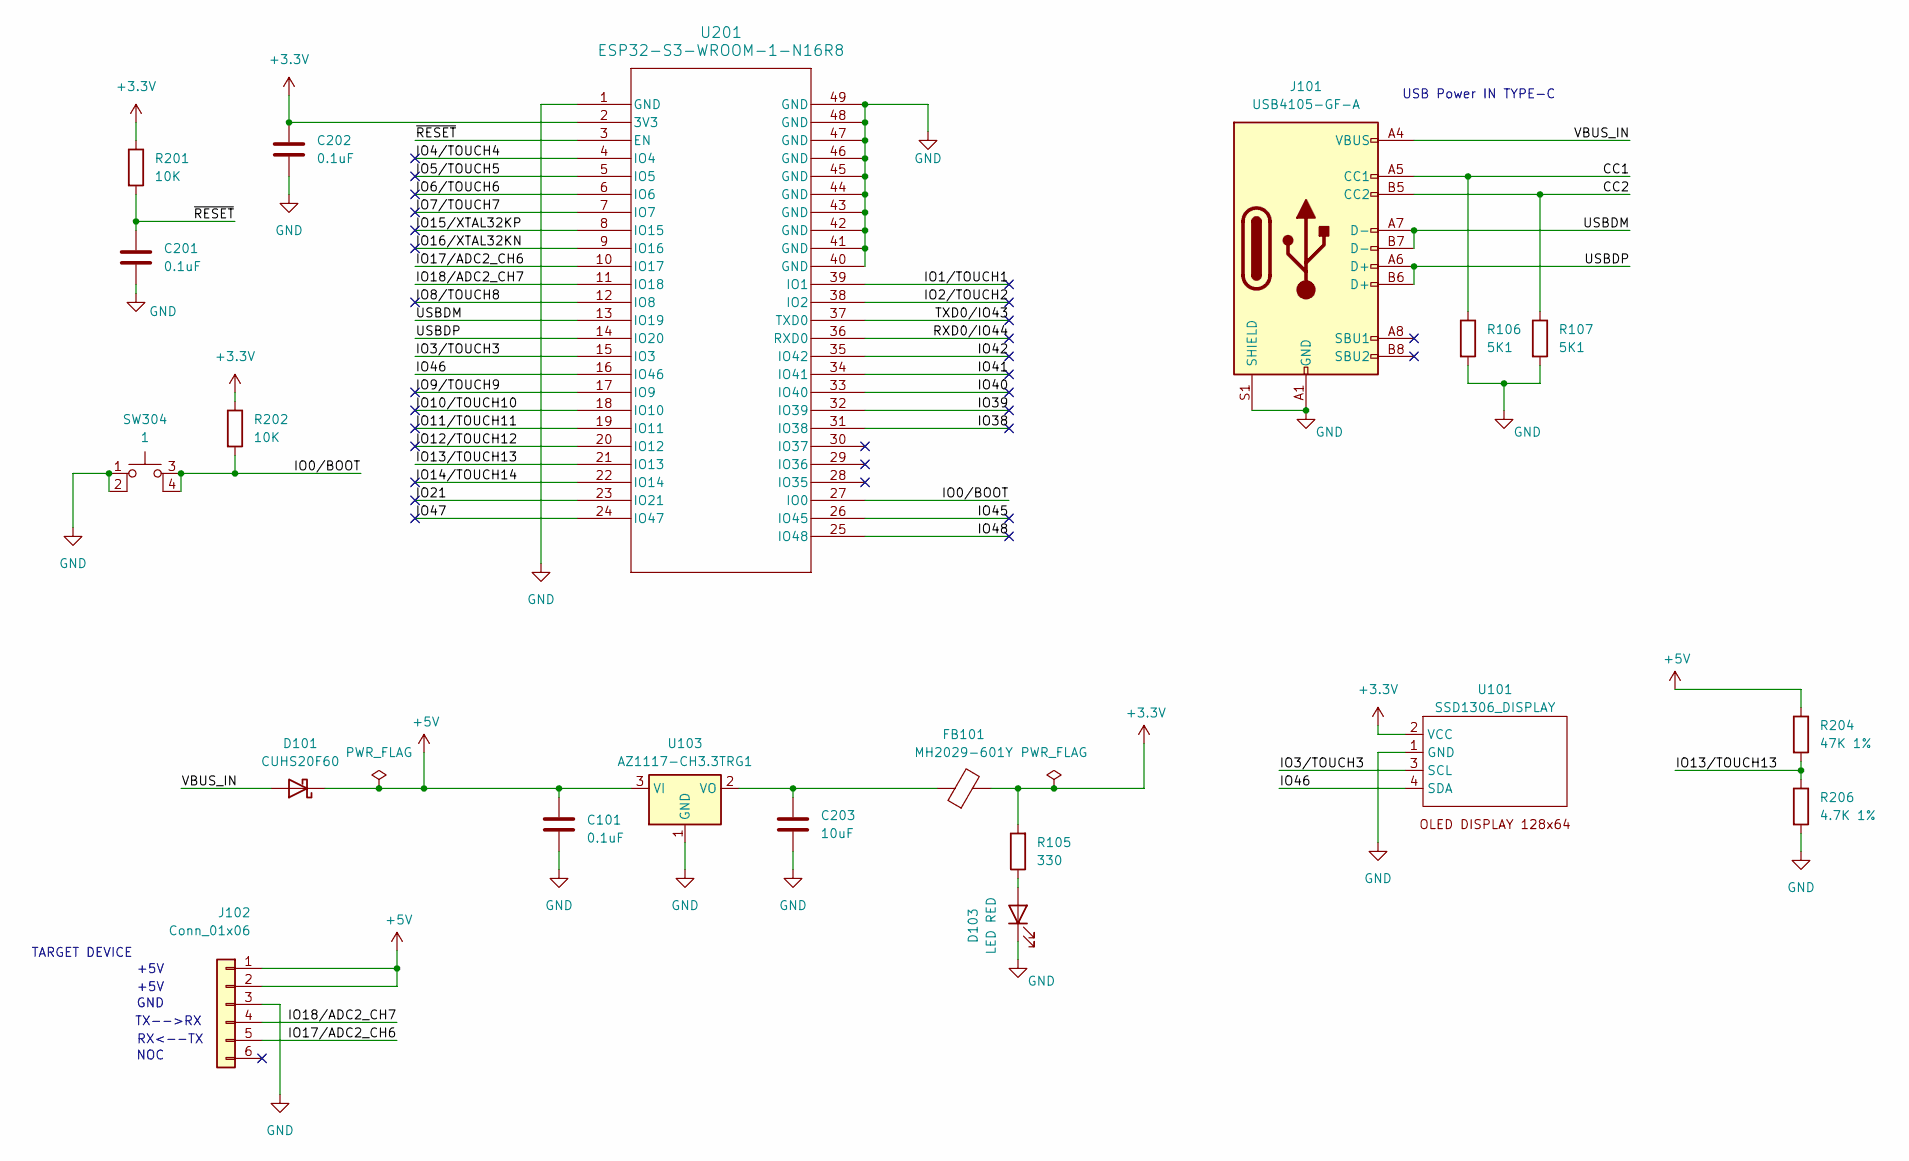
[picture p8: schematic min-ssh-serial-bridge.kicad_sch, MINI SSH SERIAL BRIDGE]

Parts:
C101, C201, C202: 0.1uF; C_0603_1608Metric; digikey 311-1343-1-ND
C203: 10uF; C_0805_2012Metric; digikey 311-1355-1-ND
D101: CUHS20F60; D_PowerDI-123; digikey 264-CUHS20F60H3FCT-ND
D103: LED RED; LED_0603_1608Metric; digikey 3147-B1931URO-20D000114U1930CT-ND
FB101: MH2029-601Y; L_0805_2012Metric; digikey MH2029-601YCT-ND
J101: USB4105-GF-A; USB_C_5077CR-16-SMC2-BK-TR; digikey 2073-USB4105-GF-ACT-ND
J102: Conn_01x06; PinHeader_1x06_P2.54mm_Vertical; digikey S5442-ND
R105: 330; R_0603_1608Metric; digikey 13-RC0603JR-13330RLCT-ND
R106, R107: 5K1; R_0603_1608Metric; digikey 311-5.10KHRCT-ND
R201, R202: 10K; R_0603_1608Metric; digikey 311-10.0KHRCT-ND
R204: 47K 1%; R_0603_1608Metric; digikey 311-47.0KHRCT-ND
R206: 4.7K 1%; R_0603_1608Metric; digikey 311-4.70KHRCT-ND
SW304: 1; SW_SKRPACE010_4mm_3mm; digikey P12298SCT-ND
U101: SSD1306_DISPLAY; OLED I2C DISPLAY
U103: AZ1117-CH3.3TRG1; SOT-223-3_TabPin2; digikey AZ1117CH-3.3TRG1DICT-ND
U201: ESP32-S3-WROOM-1-N16R8; ESP32-S3-WROOM-1_EXP; digikey 1965-ESP32-S3-WROOM-1-N16R8CT-ND

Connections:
+3.3V: C202.1, FB101.2, R105.2, R201.1, R202.1, U101.2 (VCC), U201.2 (3V3)
+5V: C101.1, D101.1 (K), J102.1, J102.2, R204.1, U103.3 (VI)
/CC1: J101.A5 (CC1), R106.1
/CC2: J101.B5 (CC2), R107.1
/IO0/BOOT: R202.2, SW304.3, SW304.4, U201.27 (IO0)
/IO1/TOUCH1: U201.39 (IO1)
/IO2/TOUCH2: U201.38 (IO2)
/IO3/TOUCH3: U101.3 (SCL), U201.15 (IO3)
/IO4/TOUCH4: U201.4 (IO4)
/IO5/TOUCH5: U201.5 (IO5)
/IO6/TOUCH6: U201.6 (IO6)
/IO7/TOUCH7: U201.7 (IO7)
/IO8/TOUCH8: U201.12 (IO8)
/IO9/TOUCH9: U201.17 (IO9)
/IO10/TOUCH10: U201.18 (IO10)
/IO11/TOUCH11: U201.19 (IO11)
/IO12/TOUCH12: U201.20 (IO12)
/IO13/TOUCH13: R204.2, R206.1, U201.21 (IO13)
/IO14/TOUCH14: U201.22 (IO14)
/IO15/XTAL32KP: U201.8 (IO15)
/IO16/XTAL32KN: U201.9 (IO16)
/IO17/ADC2_CH6: J102.5, U201.10 (IO17)
/IO18/ADC2_CH7: J102.4, U201.11 (IO18)
/IO21: U201.23 (IO21)
/IO38: U201.31 (IO38)
/IO39: U201.32 (IO39)
/IO40: U201.33 (IO40)
/IO41: U201.34 (IO41)
/IO42: U201.35 (IO42)
/IO45: U201.26 (IO45)
/IO46: U101.4 (SDA), U201.16 (IO46)
/IO47: U201.24 (IO47)
/IO48: U201.25 (IO48)
/RXD0/IO44: U201.36 (RXD0)
/TXD0/IO43: U201.37 (TXD0)
/USBDM: J101.A7 (D-), J101.B7 (D-), U201.13 (IO19)
/USBDP: J101.A6 (D+), J101.B6 (D+), U201.14 (IO20)
/VBUS_IN: D101.2 (A), J101.A4 (VBUS), J101.A9 (VBUS), J101.B4 (VBUS), J101.B9 (VBUS)
/~RESET: C201.1, R201.2, U201.3 (EN)
GND: C101.2, C201.2, C202.2, C203.2, D103.1 (K), J101.A1 (GND), J101.A12 (GND), J101.B1 (GND), J101.B12 (GND), J101.S1 (SHIELD), J102.3, R106.2, R107.2, R206.2, SW304.1, SW304.2, U101.1 (GND), U103.1 (GND), U201.1 (GND), U201.40 (GND), U201.41 (GND), U201.42 (GND), U201.43 (GND), U201.44 (GND), U201.45 (GND), U201.46 (GND), U201.47 (GND), U201.48 (GND), U201.49 (GND)
unnamed: D103.2 (A), R105.1
unnamed: C203.1, FB101.1, U103.2 (VO)

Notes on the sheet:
RX<--TX
USB Power IN TYPE-C
TARGET DEVICE
NOC
+5V
TX-->RX
GND

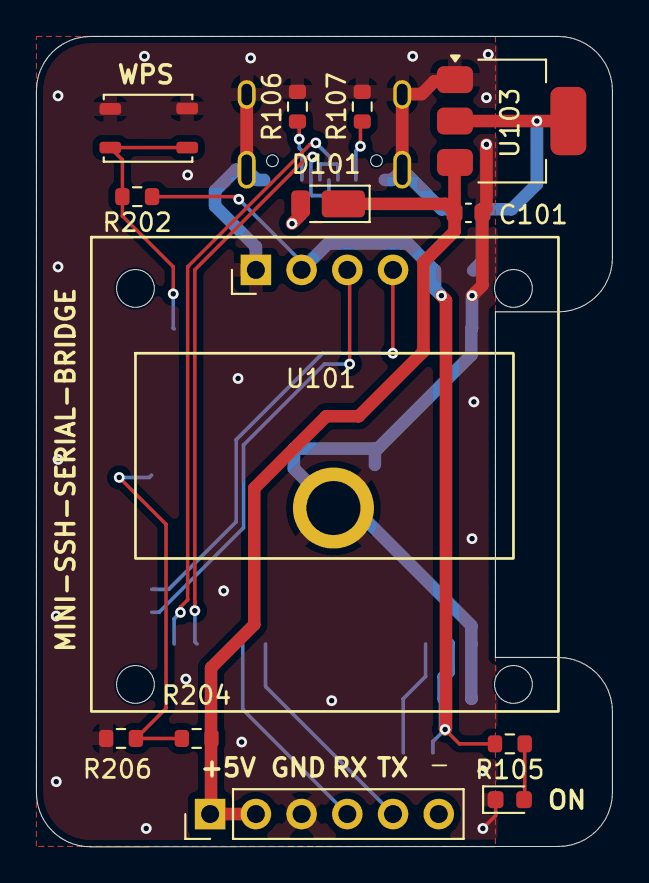
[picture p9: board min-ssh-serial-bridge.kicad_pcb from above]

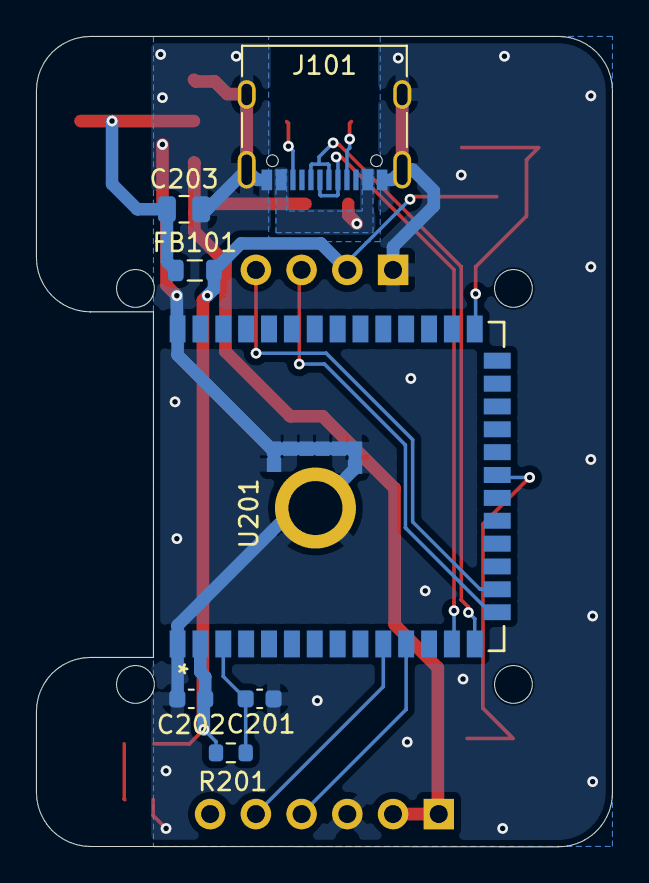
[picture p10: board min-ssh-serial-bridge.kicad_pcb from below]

Board: 2 copper layers, 32.0 x 45.0 mm, 20 parts (7 on the bottom side), 17 nets.

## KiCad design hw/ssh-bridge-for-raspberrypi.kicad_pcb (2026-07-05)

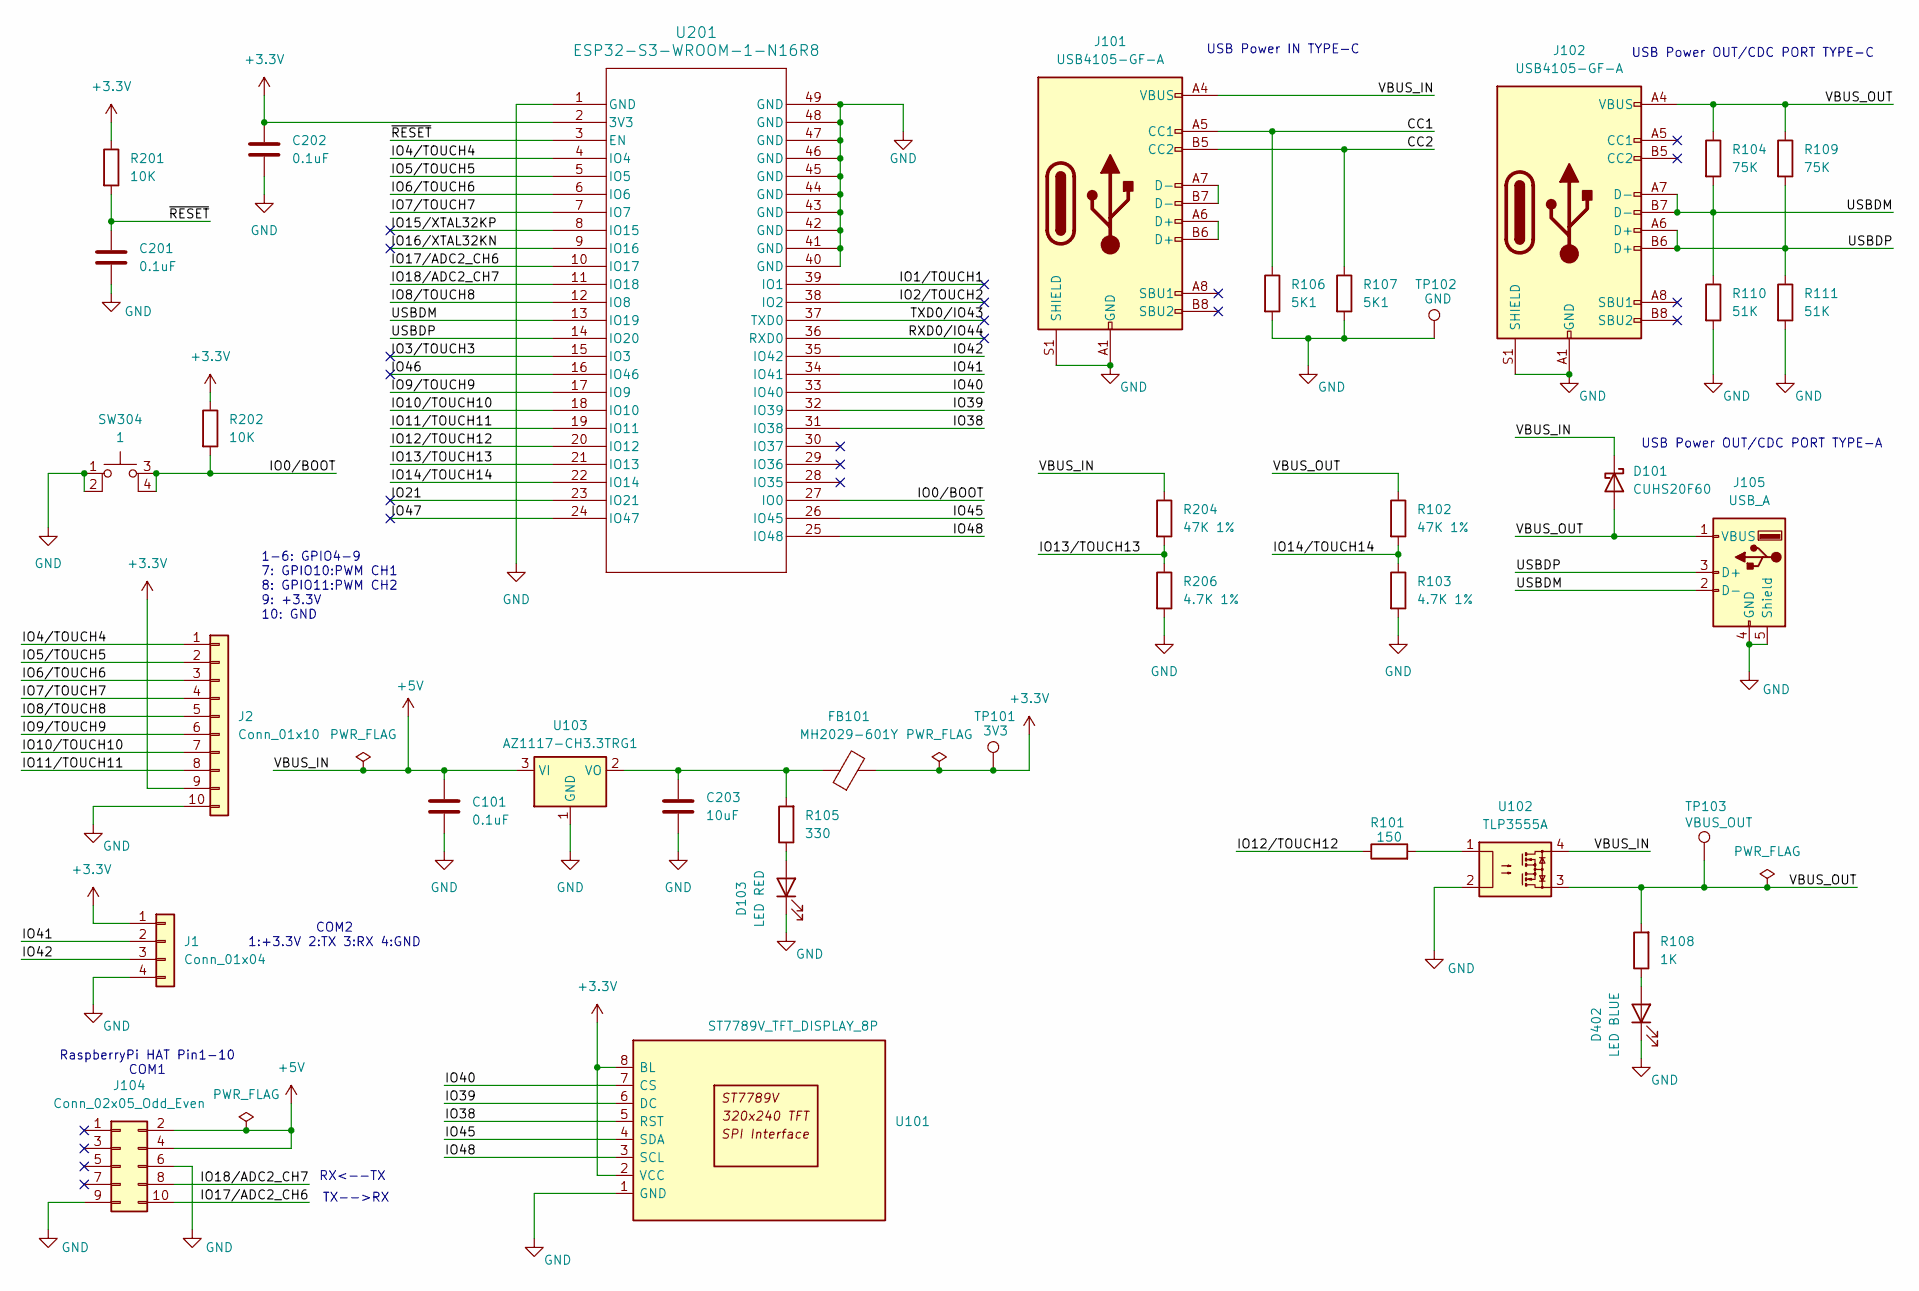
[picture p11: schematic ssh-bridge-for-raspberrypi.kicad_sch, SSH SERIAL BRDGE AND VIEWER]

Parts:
C101, C201, C202: 0.1uF; C_0603_1608Metric; digikey 311-1343-1-ND
C203: 10uF; C_0805_2012Metric; digikey 311-1355-1-ND
D101: CUHS20F60; D_PowerDI-123; digikey 264-CUHS20F60H3FCT-ND
D103: LED RED; LED_0603_1608Metric; digikey 3147-B1931URO-20D000114U1930CT-ND
D402: LED BLUE; LED_0603_1608Metric; digikey 3147-B1931NB--20C007614U1930CT-ND
FB101: MH2029-601Y; L_0805_2012Metric; digikey MH2029-601YCT-ND
J1: Conn_01x04; PinHeader_1x04_P2.54mm_Vertical; digikey 732-5317-ND
J2: Conn_01x10; PinHeader_1x10_P2.54mm_Vertical; digikey 732-2670-ND
J101, J102: USB4105-GF-A; USB_C_5077CR-16-SMC2-BK-TR; digikey 2073-USB4105-GF-ACT-ND
J104: Conn_02x05_Odd_Even; PinHeader_2x05_P2.54mm_Vertical; digikey 732-2672-ND
J105: USB_A; USB_A_5075AR-04; digikey ED2989-ND
R101: 150; R_0603_1608Metric; digikey 13-RC0603FR-13150RLCT-ND
R102, R204: 47K 1%; R_0603_1608Metric; digikey 311-47.0KHRCT-ND
R103, R206: 4.7K 1%; R_0603_1608Metric; digikey 311-4.70KHRCT-ND
R104, R109: 75K; R_0603_1608Metric; digikey 311-75.0KHRCT-ND
R105: 330; R_0603_1608Metric; digikey 13-RC0603JR-13330RLCT-ND
R106, R107: 5K1; R_0603_1608Metric; digikey 311-5.10KHRCT-ND
R108: 1K; R_0603_1608Metric; digikey 311-1.00KHRCT-ND
R110, R111: 51K; R_0603_1608Metric; digikey 311-51.0KHRCT-ND
R201, R202: 10K; R_0603_1608Metric; digikey 311-10.0KHRCT-ND
SW304: 1; SW_SKRPACE010_4mm_3mm; digikey P12298SCT-ND
TP101: 3V3; TestPoint_Pad_D1.0mm
TP102: GND; TestPoint_Pad_D1.0mm
TP103: VBUS_OUT; TestPoint_Pad_D1.0mm
U101: ST7789V_TFT_DISPLAY_8P; ST7789V TFT SPI DISPLAY 320x240 GMT020-02-8P
U102: TLP3555A; DIP-4_W7.62mm; digikey TLP3555A(F-ND
U103: AZ1117-CH3.3TRG1; SOT-223-3_TabPin2; digikey AZ1117CH-3.3TRG1DICT-ND
U201: ESP32-S3-WROOM-1-N16R8; ESP32-S3-WROOM-1_EXP; digikey 1965-ESP32-S3-WROOM-1-N16R8CT-ND

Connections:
+3.3V: C202.1, FB101.2, J1.1, J2.9, R201.1, R202.1, TP101.1 (1_1), U101.2 (VCC), U101.8 (BL), U201.2 (3V3)
+5V: C101.1, D101.1 (K), J101.A4 (VBUS), J101.A9 (VBUS), J101.B4 (VBUS), J101.B9 (VBUS), J104.2, J104.4, R204.1, U102.4, U103.3 (VI)
/CC1: J101.A5 (CC1), R106.1
/CC2: J101.B5 (CC2), R107.1
/IO0/BOOT: R202.2, SW304.3, SW304.4, U201.27 (IO0)
/IO1/TOUCH1: U201.39 (IO1)
/IO2/TOUCH2: U201.38 (IO2)
/IO3/TOUCH3: U201.15 (IO3)
/IO4/TOUCH4: J2.1, U201.4 (IO4)
/IO5/TOUCH5: J2.2, U201.5 (IO5)
/IO6/TOUCH6: J2.3, U201.6 (IO6)
/IO7/TOUCH7: J2.4, U201.7 (IO7)
/IO8/TOUCH8: J2.5, U201.12 (IO8)
/IO9/TOUCH9: J2.6, U201.17 (IO9)
/IO10/TOUCH10: J2.7, U201.18 (IO10)
/IO11/TOUCH11: J2.8, U201.19 (IO11)
/IO12/TOUCH12: R101.1, U201.20 (IO12)
/IO13/TOUCH13: R204.2, R206.1, U201.21 (IO13)
/IO14/TOUCH14: R102.2, R103.1, U201.22 (IO14)
/IO15/XTAL32KP: U201.8 (IO15)
/IO16/XTAL32KN: U201.9 (IO16)
/IO17/ADC2_CH6: J104.10, U201.10 (IO17)
/IO18/ADC2_CH7: J104.8, U201.11 (IO18)
/IO21: U201.23 (IO21)
/IO38: U101.5 (RST), U201.31 (IO38)
/IO39: U101.6 (DC), U201.32 (IO39)
/IO40: U101.7 (CS), U201.33 (IO40)
/IO41: J1.2, U201.34 (IO41)
/IO42: J1.3, U201.35 (IO42)
/IO45: U101.4 (SDA), U201.26 (IO45)
/IO46: U201.16 (IO46)
/IO47: U201.24 (IO47)
/IO48: U101.3 (SCL), U201.25 (IO48)
/RXD0/IO44: U201.36 (RXD0)
/TXD0/IO43: U201.37 (TXD0)
/USBDM: J102.A7 (D-), J102.B7 (D-), J105.2 (D-), R104.2, R110.1, U201.13 (IO19)
/USBDP: J102.A6 (D+), J102.B6 (D+), J105.3 (D+), R109.2, R111.1, U201.14 (IO20)
/VBUS_OUT: D101.2 (A), J102.A4 (VBUS), J102.A9 (VBUS), J102.B4 (VBUS), J102.B9 (VBUS), J105.1 (VBUS), R102.1, R104.1, R108.2, R109.1, TP103.1 (1_1), U102.3
/~RESET: C201.1, R201.2, U201.3 (EN)
GND: C101.2, C201.2, C202.2, C203.2, D103.1 (K), D402.1 (K), J1.4, J2.10, J101.A1 (GND), J101.A12 (GND), J101.B1 (GND), J101.B12 (GND), J101.S1 (SHIELD), J102.A1 (GND), J102.A12 (GND), J102.B1 (GND), J102.B12 (GND), J102.S1 (SHIELD), J104.6, J104.9, J105.4 (GND), J105.5 (Shield), R103.2, R106.2, R107.2, R110.2, R111.2, R206.2, SW304.1, SW304.2, TP102.1 (1_1), U101.1 (GND), U102.2, U103.1 (GND), U201.1 (GND), U201.40 (GND), U201.41 (GND), U201.42 (GND), U201.43 (GND), U201.44 (GND), U201.45 (GND), U201.46 (GND), U201.47 (GND), U201.48 (GND), U201.49 (GND)
unnamed: D103.2 (A), R105.1
unnamed: D402.2 (A), R108.1
unnamed: J101.A6 (D+), J101.B6 (D+)
unnamed: J101.A7 (D-), J101.B7 (D-)
unnamed: R101.2, U102.1
unnamed: C203.1, FB101.1, R105.2, U103.2 (VO)

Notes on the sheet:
USB Power OUT/CDC PORT TYPE-A
COM2 1:+3.3V 2:TX 3:RX 4:GND
1-6: GPIO4-9 7: GPIO10:PWM CH1 8: GPIO11:PWM CH2 9: +3.3V 10: GND
USB Power IN TYPE-C
RaspberryPi HAT Pin1-10 COM1
TX-->RX
USB Power OUT/CDC PORT TYPE-C
RX<--TX

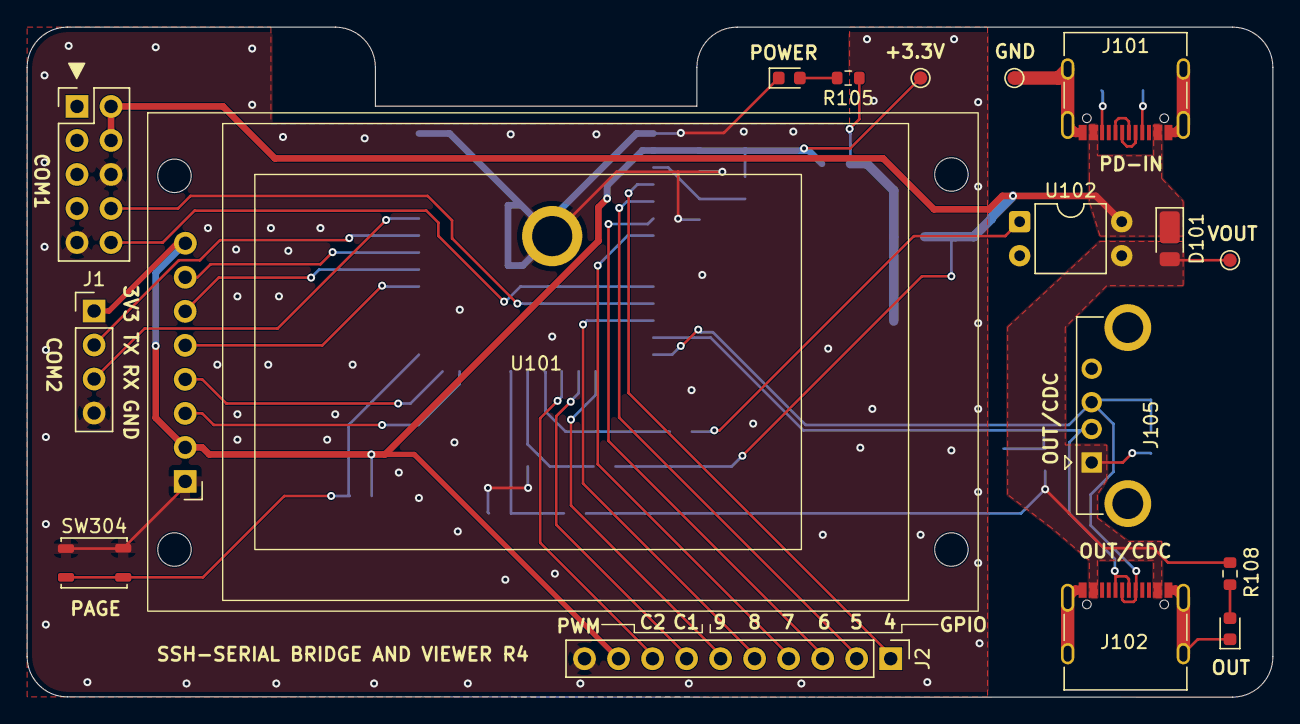
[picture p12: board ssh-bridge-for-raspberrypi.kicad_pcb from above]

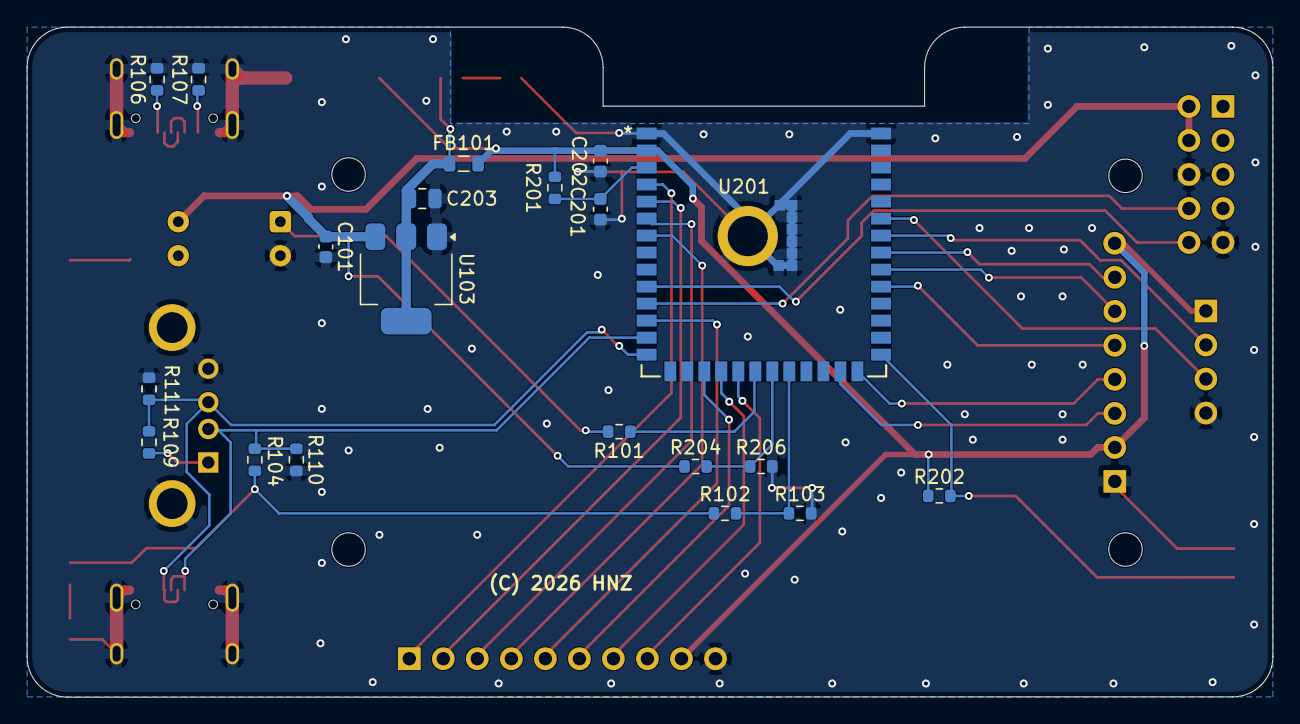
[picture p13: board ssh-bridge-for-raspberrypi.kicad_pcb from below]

Board: 2 copper layers, 93.0 x 50.0 mm, 37 parts (20 on the bottom side), 36 nets.

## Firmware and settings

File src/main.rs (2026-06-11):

use log::info;
use esp_idf_svc::hal::ledc::LedcDriver;
use esp_idf_svc::hal::ledc::LedcTimerDriver;
use esp_idf_svc::hal::ledc::config::TimerConfig;
use esp_idf_svc::sntp::{EspSntp, SyncStatus, SntpConf, OperatingMode, SyncMode};
use chrono::{DateTime, Utc};
use esp_idf_hal::{gpio::*, prelude::*};
use esp_idf_hal::adc::attenuation::DB_11;
use esp_idf_hal::adc::oneshot::{AdcDriver, AdcChannelDriver};
use esp_idf_hal::adc::oneshot::config::AdcChannelConfig;
use esp_idf_hal::temp_sensor::{TempSensorConfig, TempSensorDriver};
use esp_idf_hal::i2c::{I2cConfig, I2cDriver};
use std::time::{Duration, SystemTime};
use std::thread;

mod wifi;
mod syslogger;
pub mod usb_host;
mod httpserver;
mod gpio_ctrl;
pub mod serial_display;
mod btn_ctrl;
mod boot_log;
mod mini_display;

#[toml_cfg::toml_config]
pub struct Config {
    #[default("")]
    wifi_ssid: &'static str,
    #[default("")]
    wifi_psk: &'static str,
    #[default("dhcp")]
    ip_mode: &'static str,
    #[default("")]
    ip_address: &'static str,
    #[default("255.255.255.0")]
    subnet_mask: &'static str,
    #[default("")]
    gateway: &'static str,
    #[default("")]
    dns: &'static str,
    #[default("")]
    syslog_server: &'static str,
    #[default("false")]
    syslog_enable: &'static str,
    #[default("esp32")]
    syslog_host_name: &'static str,
    #[default("app")]
    syslog_app_name: &'static str,
    #[default("admin")]
    ssh_user: &'static str,
    #[default("esp32")]
    ssh_password: &'static str,
    #[default("false")]
    wps_enable: &'static str,
    #[default("17")]
    com1_tx_pin: &'static str,
    #[default("18")]
    com1_rx_pin: &'static str,
    #[default("115200")]
    com1_baud: &'static str,
    #[default("19")]
    com2_tx_pin: &'static str,
    #[default("20")]
    com2_rx_pin: &'static str,
    #[default("115200")]
    com2_baud: &'static str,
    #[default("true")]
    cdc_enable: &'static str,
    #[default("115200")]
    cdc_baud: &'static str,
    #[default("true")]
    cdc_retry_enable: &'static str,
    #[default("5")]
    cdc_retry_interval: &'static str,
    #[default("true")]
    display_enable: &'static str,
    #[default("com1")]
    display_port: &'static str,
    #[default("false")]
    mini_display_enable: &'static str,
    #[default("true")]
    pwm_enable: &'static str,
    #[default("time.aws.com")]
    ntp_server1: &'static str,
    #[default("time.google.com")]
    ntp_server2: &'static str,
    #[default("time.cloudflare.com")]
    ntp_server3: &'static str,
    #[default("ntp.nict.jp")]
    ntp_server4: &'static str,
    #[default("80.098")]
    adc_conversion_factor: &'static str,
}

fn main() {
    // It is necessary to call this function once. Otherwise some patches to the runtime
    // implemented by esp-idf-sys might not link properly. See https://github.com/esp-rs/esp-idf-template/issues/71
    esp_idf_svc::sys::link_patches();

    // Peripherals Initialize
    let peripherals = Peripherals::take().unwrap();

    // ── Serial display on ST7789V (SPI3, 240x320) ─────────────────────────
    // Display init is deferred until after NVS config is loaded (see below)

    // NVS flash init (required before WiFi for RF calibration data)
    unsafe { esp_idf_sys::nvs_flash_init(); }
    // Record reset reason and boot count to NVS before anything else
    let (boot_count, reset_reason) = boot_log::record_boot();
    println!("Boot #{}, reset reason: {}", boot_count, reset_reason);
    // Load config from NVS (overrides cfg.toml defaults where NVS keys are set)
    let cfg_defaults = httpserver::NvsConfig {
        wifi_ssid:     CONFIG.wifi_ssid.to_string(),
        wifi_psk:      CONFIG.wifi_psk.to_string(),
        ip_mode:       CONFIG.ip_mode.to_string(),
        ip_address:    CONFIG.ip_address.to_string(),
        subnet_mask:   CONFIG.subnet_mask.to_string(),
        gateway:       CONFIG.gateway.to_string(),
        dns:           CONFIG.dns.to_string(),
        syslog_server: CONFIG.syslog_server.to_string(),
        syslog_enable: CONFIG.syslog_enable.to_string(),
        syslog_host_name: CONFIG.syslog_host_name.to_string(),
        syslog_app_name: CONFIG.syslog_app_name.to_string(),
        ssh_user:      CONFIG.ssh_user.to_string(),
        ssh_password:  CONFIG.ssh_password.to_string(),
        wps_enable:    CONFIG.wps_enable.to_string(),
        com1_tx_pin:   CONFIG.com1_tx_pin.to_string(),
        com1_rx_pin:   CONFIG.com1_rx_pin.to_string(),
        com1_baud:     CONFIG.com1_baud.to_string(),
        com2_tx_pin:   CONFIG.com2_tx_pin.to_string(),
        com2_rx_pin:   CONFIG.com2_rx_pin.to_string(),
        com2_baud:     CONFIG.com2_baud.to_string(),
        cdc_enable:    CONFIG.cdc_enable.to_string(),
        cdc_baud:      CONFIG.cdc_baud.to_string(),
        cdc_retry_enable: CONFIG.cdc_retry_enable.to_string(),
        cdc_retry_interval: CONFIG.cdc_retry_interval.to_string(),
        display_enable: CONFIG.display_enable.to_string(),
        display_port:  CONFIG.display_port.to_string(),
        mini_display_enable: CONFIG.mini_display_enable.to_string(),
        pwm_enable:    CONFIG.pwm_enable.to_string(),
        ntp_server1:   CONFIG.ntp_server1.to_string(),
        ntp_server2:   CONFIG.ntp_server2.to_string(),
        ntp_server3:   CONFIG.ntp_server3.to_string(),
        ntp_server4:   CONFIG.ntp_server4.to_string(),
    };
    let mut nvs_config = httpserver::load_config(cfg_defaults.clone());

    // Parse ADC conversion factor from config (not stored in NVS)
    let adc_conversion_factor: f32 = CONFIG.adc_conversion_factor.parse().unwrap_or(80.098);

    // Create GPIO/PWM shared state (used by button control, display, and HTTP server)
    let gpio_pwm_state = gpio_ctrl::GpioPwmState::new();

    // ── Button control thread — always started (GPIO0 / BOOT button) ──────────
    // Short press (< 3s): cycle display page
    // Medium press (3s ~ 10s): toggle DC OUT (GPIO12) ON/OFF
    // Very long press (≥ 10s): factory reset to cfg.toml defaults
    btn_ctrl::start_button_thread(peripherals.pins.gpio0, gpio_pwm_state.clone());

    // ── Mini Display init (SSD1306, only when enabled) ────────────────────
    if nvs_config.mini_display_enable == "true" {
        info!("Initializing mini display (SSD1306)...");
        let i2c_config = I2cConfig::new().baudrate(400.kHz().into());
        match I2cDriver::new(
            peripherals.i2c0,
            peripherals.pins.gpio46,  // SDA
            peripherals.pins.gpio3,   // SCL
            &i2c_config,
        ) {
            Ok(i2c) => {
                mini_display::start_mini_display_thread(i2c);
                info!("Mini display (SSD1306) initialized");
            }
            Err(e) => {
                info!("Failed to initialize I2C for mini display: {:?}", e);
            }
        }
    } else {
        info!("Mini display disabled");
    }

    // ── Display init (only when enabled) ──────────────────────────────────
    if nvs_config.display_enable == "true" {
        let com1_buf = serial_display::SerialRxBuffer::new();
        let com2_buf = serial_display::SerialRxBuffer::new();
        let usb_buf  = serial_display::SerialRxBuffer::new();
        usb_host::set_display_rx_bufs(com1_buf.clone(), com2_buf.clone(), usb_buf.clone());
        serial_display::start_display_thread(
            peripherals.spi3,
            peripherals.pins.gpio48,
            peripherals.pins.gpio45,
            peripherals.pins.gpio40,
            peripherals.pins.gpio39,
            peripherals.pins.gpio38,
            com1_buf,
            com2_buf,
            usb_buf,
        );
        usb_host::set_display_port(&nvs_config.display_port);
        info!("Display enabled, port: {}", nvs_config.display_port);
    } else {
        info!("Display disabled");
    }

    // WiFi connect (using NVS config — falls back to cfg.toml if not set)
    // When wps_enable=true and SSID is empty, WPS PBC is used to obtain credentials.
    let wifi_dev = if nvs_config.wps_enable == "true" && nvs_config.wifi_ssid.is_empty() {
        println!("WPS enabled and SSID not configured — starting WPS PBC (press WPS button on router)...");
        mini_display::show_message("WPS", "Connecting...\nPress WPS button\non router");
        let result = match wifi::wifi_connect_wps(peripherals.modem) {
            Ok((w, ssid, pass)) => {
                println!("WPS success: SSID={}", ssid);
                httpserver::nvs_write_wifi_creds(&ssid, &pass);
                nvs_config.wifi_ssid = ssid;
                nvs_config.wifi_psk  = pass;
                Ok(w)
            }
            Err(e) => {
                println!("WPS failed: {:?}", e);
                Err(e)
            }
        };
        mini_display::clear_message();
        result
    } else {
        println!("Connecting to WiFi: {}", nvs_config.wifi_ssid);
        wifi::wifi_connect(peripherals.modem, &nvs_config.wifi_ssid, &nvs_config.wifi_psk)
    };

    // Create shared status and populate IP/SSID after WiFi connects
    let dev_status = httpserver::StatusInfo::new();
    match &wifi_dev {
        Ok(w) => {
            // Apply static IP unconditionally (interface config, independent of connection state)
            if nvs_config.ip_mode == "static" {
                match wifi::configure_static_ip(w, &nvs_config.ip_address, &nvs_config.subnet_mask, &nvs_config.gateway, &nvs_config.dns) {
                    Ok(_) => println!("Static IP configured"),
                    Err(e) => println!("Failed to set static IP: {:?}, falling back to DHCP", e),
                }
            }
            if w.is_connected().unwrap_or(false) {
                println!("WiFi connected.");
                if let Ok(ip_info) = w.sta_netif().get_ip_info() {
                    println!("IP address: {}", ip_info.ip);
                    dev_status.set_wifi(
                        &ip_info.ip.to_string(),
                        &nvs_config.wifi_ssid,
                        wifi::get_rssi(),
                    );
                    if nvs_config.mini_display_enable == "true" {
                        let com1_baud = nvs_config.com1_baud.parse().unwrap_or(0);
                        let rssi = wifi::get_rssi() as i8;
                        mini_display::update_display_info(true, &ip_info.ip.to_string(), rssi, 0.0, com1_baud);
                    }
                }
            } else {
                println!("WiFi initialized (AP not reachable yet — will retry every 30 s).");
                if nvs_config.mini_display_enable == "true" {
                    let com1_baud = nvs_config.com1_baud.parse().unwrap_or(0);
                    mini_display::update_display_info(false, "---", 0, 0.0, com1_baud);
                }
            }
        },
        Err(e) => {
            println!("WiFi init failed: {:?}", e);
            if nvs_config.mini_display_enable == "true" {
                let com1_baud = nvs_config.com1_baud.parse().unwrap_or(0);
                mini_display::update_display_info(false, "---", 0, 0.0, com1_baud);
            }
        }
    }

    // Start WiFi monitor thread — reconnects every 30 s when not associated.
    // Start after a 15 s grace period so the initial connect attempt can settle.
    if wifi_dev.is_ok() {
        wifi::start_wifi_monitor_thread(15, 30);
    }

    // Start HTTP config server (login protected, NVS-backed settings)
    let config_state = httpserver::ConfigState::new(nvs_config.clone(), cfg_defaults, dev_status.clone(), gpio_pwm_state.clone());
    let _http_server = match httpserver::start_http_server(config_state) {
        Ok(s)  => { println!("HTTP config server started on port 80"); Some(s) }
        Err(e) => { println!("HTTP config server failed to start: {:?}", e); None }
    };

    // Start WebSocket sender thread (drains ring buffers → WS clients)
    usb_host::start_ws_sender_thread();

    // Provide info-page data to the display thread (only when display is enabled)
    if nvs_config.display_enable == "true" {
        serial_display::set_display_aux(serial_display::DisplayAux {
            status: dev_status.clone(),
            gpio_state: gpio_pwm_state.clone(),
            com1_baud: nvs_config.com1_baud.clone(),
            com1_tx: nvs_config.com1_tx_pin.clone(),
            com1_rx: nvs_config.com1_rx_pin.clone(),
            com2_baud: nvs_config.com2_baud.clone(),
            com2_tx: nvs_config.com2_tx_pin.clone(),
            com2_rx: nvs_config.com2_rx_pin.clone(),
            cdc_baud: nvs_config.cdc_baud.clone(),
        });
    }

    // Syslog init (after wifi is up)
    if nvs_config.syslog_enable == "true" {
        println!("Initializing syslog to {} ...", nvs_config.syslog_server);
        thread::sleep(Duration::from_secs(5));
        match syslogger::init_logger(&nvs_config.syslog_server, &nvs_config.syslog_enable, &nvs_config.syslog_host_name, &nvs_config.syslog_app_name) {
            Ok(_) => {
                log::set_max_level(log::LevelFilter::Info);
                println!("Syslog logger initialized successfully");
                info!("Syslog logger initialized successfully");
                if let Ok(w) = wifi_dev.as_ref() {
                    if let Ok(ip_info) = w.sta_netif().get_ip_info() {
                        info!("WiFi IP address: {}", ip_info.ip);
                    }
                }
            },
            Err(e) => {
                println!("Failed to initialize syslog: {:?}, falling back to ESP logger", e);
                let _ = esp_idf_svc::log::EspLogger::initialize_default();
                log::set_max_level(log::LevelFilter::Info);
            }
        }
    } else {
        esp_idf_svc::log::EspLogger::initialize_default();
        log::set_max_level(log::LevelFilter::Info);
        info!("Using default ESP console logger (syslog disabled)");
    }

    // NTP Server
    let ntp1: &'static str = Box::leak(nvs_config.ntp_server1.clone().into_boxed_str());
    let ntp2: &'static str = Box::leak(nvs_config.ntp_server2.clone().into_boxed_str());
    let ntp3: &'static str = Box::leak(nvs_config.ntp_server3.clone().into_boxed_str());
    let ntp4: &'static str = Box::leak(nvs_config.ntp_server4.clone().into_boxed_str());
    let sntp_conf = SntpConf {
        servers: [ntp1, ntp2, ntp3, ntp4],
        operating_mode: OperatingMode::Poll,
        sync_mode: SyncMode::Immediate,
    };
    let ntp = EspSntp::new(&sntp_conf).unwrap();

    // NTP Sync
    info!("NTP Sync Start..");

    // wait for sync
    let mut sync_count = 0;
    while ntp.get_sync_status() != SyncStatus::Completed {
        sync_count += 1;
        if sync_count > 1000 {
            info!("NTP Sync Timeout");
            break;
        }
        thread::sleep(Duration::from_millis(10));
    }
    let now = SystemTime::now();
    let dt_now : DateTime<Utc> = now.into();
    let formatted = format!("{}", dt_now.format("%Y-%m-%d %H:%M:%S"));
    info!("NTP Sync Completed: {}", formatted);

    // Start USB host + SSH bridge
    // Leak NVS strings to obtain &'static str required by usb_host::start.
    let ssh_user_s: &'static str = Box::leak(nvs_config.ssh_user.clone().into_boxed_str());
    let ssh_pass_s: &'static str = Box::leak(nvs_config.ssh_password.clone().into_boxed_str());
    usb_host::start(
        ssh_user_s,
        ssh_pass_s,
        nvs_config.com1_tx_pin.parse().unwrap_or(17),
        nvs_config.com1_rx_pin.parse().unwrap_or(18),
        nvs_config.com1_baud.parse().unwrap_or(115200),
        nvs_config.com2_tx_pin.parse().unwrap_or(19),
        nvs_config.com2_rx_pin.parse().unwrap_or(20),
        nvs_config.com2_baud.parse().unwrap_or(115200),
        nvs_config.cdc_enable == "true",
        nvs_config.cdc_baud.parse().unwrap_or(115200),
        nvs_config.cdc_retry_enable == "true",
        nvs_config.cdc_retry_interval.parse().unwrap_or(5),
        gpio_pwm_state.clone(),
    );

    let pwm_enabled = nvs_config.pwm_enable == "true";

    // ── GPIO 4-9, 12 output init ─────────────────────────────────────────────
    println!("Initializing GPIO 4-9,12 outputs...");
    let mut gpio_out: [PinDriver<AnyOutputPin, Output>; 7] = [
        PinDriver::output(peripherals.pins.gpio4.downgrade_output()).unwrap(),
        PinDriver::output(peripherals.pins.gpio5.downgrade_output()).unwrap(),
        PinDriver::output(peripherals.pins.gpio6.downgrade_output()).unwrap(),
        PinDriver::output(peripherals.pins.gpio7.downgrade_output()).unwrap(),
        PinDriver::output(peripherals.pins.gpio8.downgrade_output()).unwrap(),
        PinDriver::output(peripherals.pins.gpio9.downgrade_output()).unwrap(),
        PinDriver::output(peripherals.pins.gpio12.downgrade_output()).unwrap(),
    ];
    for pin in gpio_out.iter_mut() {
        pin.set_low().unwrap();
    }

    // ── PWM GPIO 10-11 (LEDC timer2/3, channel2/3) ────────────────────────
    // Box::leak makes the timer drivers 'static so LedcDriver<'static> can live
    // through the main loop inside an Option.
    let (mut pwm_gpio10_opt, max_duty_gpio10, mut pwm_gpio11_opt, max_duty_gpio11) = if pwm_enabled {
        println!("Initializing PWM GPIO 10-11...");
        let tc10 = TimerConfig::default().frequency(1.kHz().into())
            .resolution(esp_idf_hal::ledc::config::Resolution::Bits14);
        let td2: &'static _ = Box::leak(Box::new(
            LedcTimerDriver::new(peripherals.ledc.timer2, &tc10).unwrap()
        ));
        let mut p10 = LedcDriver::new(peripherals.ledc.channel2, td2, peripherals.pins.gpio10).unwrap();
        p10.set_duty(0).expect("Set duty failure gpio10");
        let max10 = p10.get_max_duty();
        let tc11 = TimerConfig::default().frequency(1.kHz().into())
            .resolution(esp_idf_hal::ledc::config::Resolution::Bits14);
        let td3: &'static _ = Box::leak(Box::new(
            LedcTimerDriver::new(peripherals.ledc.timer3, &tc11).unwrap()
        ));
        let mut p11 = LedcDriver::new(peripherals.ledc.channel3, td3, peripherals.pins.gpio11).unwrap();
        p11.set_duty(0).expect("Set duty failure gpio11");
        let max11 = p11.get_max_duty();
        info!("PWM gpio10 max_duty: {}, gpio11 max_duty: {}", max10, max11);
        (Some(p10), max10, Some(p11), max11)
    } else {
        info!("PWM disabled (gpio10, gpio11 not initialized)");
        (None, 0, None, 0)
    };

    // ── ADC2 init ─────────────────────────────────────────────
    let adc2 = AdcDriver::new(peripherals.adc2).unwrap();
    let adc_config = AdcChannelConfig {
        attenuation: DB_11,
        ..Default::default()
    };

    // ── ADC2 Channel 2 (GPIO13) init ─────────────────────────────────────────────
    let mut adc13_pin = AdcChannelDriver::new(&adc2, peripherals.pins.gpio13, &adc_config).unwrap();

    // ADC2 Channel 3 (GPIO14) init ─────────────────────────────────────────────
    let mut adc14_pin = AdcChannelDriver::new(&adc2, peripherals.pins.gpio14, &adc_config).unwrap();

    // ── GPIO1 input: power source detection (HIGH=DC jack, LOW=USB) ───────
    let gpio1_power = PinDriver::input(peripherals.pins.gpio1).unwrap();
    // gpio1_power.set_pull(Pull::Up).unwrap();　// ESP32-S3 has an internal pull-up on GPIO1, so external pull-up is not required for reliable reading. Enable if needed.
    let power_from_dc = gpio1_power.is_high();
    if power_from_dc {
        info!("Power source: DC jack input");
    } else {
        info!("Power source: USB (no DC jack input)");
    }
    let mut last_power_from_dc = power_from_dc;

    // ADC conversion factor (from config) is applied in the main loop during voltage reading to convert raw ADC values to volts.
    info!("ADC conversion factor: {} (raw ADC value / this factor = voltage in volts)", adc_conversion_factor);

    // ── Internal temperature sensor init ──────────────────────────────────
    let temp_cfg = TempSensorConfig::default();
    let mut temp_sensor = TempSensorDriver::new(&temp_cfg, peripherals.temp_sensor).unwrap();
    temp_sensor.enable().unwrap();

    let mut count = 0u32;
    loop {
        // Check connection state via EspWifi before calling get_rssi(),
        // because esp_wifi_sta_get_rssi crashes (LoadProhibited) when
        // WiFi is not connected.
        let is_connected = wifi_dev.as_ref()
            .map(|w| w.is_connected().unwrap_or(false))
            .unwrap_or(false);

        // ── Apply GPIO 4-9 desired state ──────────────────────────────────
        {
            let states = gpio_pwm_state.get_gpio();
            for (i, pin) in gpio_out.iter_mut().enumerate() {
                if states[i] { pin.set_high().ok(); } else { pin.set_low().ok(); }
            }
        }

        // ── Apply PWM GPIO 10-11 desired duty (only when PWM is enabled) ──
        if let (Some(ref mut p10), Some(ref mut p11)) = (&mut pwm_gpio10_opt, &mut pwm_gpio11_opt) {
            let duties = gpio_pwm_state.get_pwm();
            let raw10 = (duties[0] as u32 * max_duty_gpio10) / 100;
            let raw11 = (duties[1] as u32 * max_duty_gpio11) / 100;
            p10.set_duty(raw10).ok();
            p11.set_duty(raw11).ok();
        }

        // ── Power source change detection (GPIO1) ────────────────────────────
        let power_from_dc = gpio1_power.is_high();
        if power_from_dc != last_power_from_dc {
            last_power_from_dc = power_from_dc;
            if power_from_dc {
                info!("Power source changed: DC jack input");
            } else {
                info!("Power source changed: USB (no DC jack input)");
            }
        }
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

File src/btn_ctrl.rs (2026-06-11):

// Button control thread — GPIO0 (BOOT button, active-low, internal pull-up)
//
// Short press      (< 3 s):       cycle display page  (no-op when display is disabled)
// Medium press     (3 s ~ 10 s):  toggle DC OUT (GPIO12) ON/OFF
// Very long press  (≥ 10 s):      erase NVS and restart → restores cfg.toml defaults

use std::thread;
use std::time::{Duration, Instant};
use log::info;
use esp_idf_hal::gpio::{Gpio0, PinDriver, Pull};
use crate::gpio_ctrl::GpioPwmState;

/// Duration in milliseconds for DC OUT toggle (3 seconds).
const DCOUT_PRESS_MS: u64 = 3000;

/// Duration in milliseconds for a long-press factory reset (10 seconds).
const FACTORY_RESET_PRESS_MS: u64 = 10000;

/// Spawn the dedicated button-control thread.
/// This is always started regardless of whether the display is enabled.
pub fn start_button_thread(btn_pin: Gpio0, gpio_pwm_state: GpioPwmState) {
    thread::Builder::new()
        .name("btn_ctrl".into())
        .stack_size(4096)
        .spawn(move || button_task(btn_pin, gpio_pwm_state))
        .expect("spawn btn_ctrl thread");
}

fn button_task(btn_pin: Gpio0, gpio_pwm_state: GpioPwmState) {
    let mut btn = PinDriver::input(btn_pin).unwrap();
    btn.set_pull(Pull::Up).unwrap();

    let mut btn_last = true;           // true = released (pin high)
    let mut press_start: Option<Instant> = None;
    let mut dcout_triggered = false;
    let mut factory_reset_triggered = false;
    let mut display_updated = false;
    let mut mini_display_updated = false;

    loop {
        let btn_now = btn.is_high(); // high = released

        if !btn_now && btn_last {
            // ── Falling edge: button just pressed ───────────────────────
            press_start = Some(Instant::now());
            dcout_triggered = false;
            factory_reset_triggered = false;
            display_updated = false;
        } else if !btn_now {
            // ── Button held ─────────────────────────────────────────────
            if let Some(start) = press_start {
                let elapsed = start.elapsed().as_millis() as u64;
                
                // Show countdown after 6 seconds (serial display)
                if elapsed >= 6000 && !display_updated {
                    let remaining = ((FACTORY_RESET_PRESS_MS - elapsed) / 1000) as i32;
                    if remaining > 0 {
                        crate::serial_display::show_system_message(
                            "FACTORY RESET",
                            &format!("Resetting to defaults\nin {} seconds...", remaining)
                        );
                        display_updated = true;
                    }
                }
                
                // Update countdown display every second
                if elapsed >= 6000 && (elapsed / 1000) != ((elapsed - 50) / 1000) {
                    let remaining = ((FACTORY_RESET_PRESS_MS - elapsed) / 1000) as i32;
                    if remaining > 0 {
                        crate::serial_display::show_system_message(
                            "FACTORY RESET",
                            &format!("Resetting to defaults\nin {} seconds...", remaining)
                        );
                    }
                }
                
                // Show countdown on mini display after 5 seconds
                if elapsed >= 5000 && !mini_display_updated {
                    let remaining = ((FACTORY_RESET_PRESS_MS - elapsed) / 1000) as i32;
                    if remaining > 0 {
                        crate::mini_display::show_message(
                            "FACTORY RESET",
                            &format!("Reset in {}s...", remaining)
                        );
                        mini_display_updated = true;
                    }
                }
                
                // Update mini display countdown every second
                if elapsed >= 5000 && elapsed < FACTORY_RESET_PRESS_MS
                    && (elapsed / 1000) != ((elapsed - 50) / 1000)
                {
                    let remaining = ((FACTORY_RESET_PRESS_MS - elapsed) / 1000) as i32;
                    if remaining > 0 {
                        crate::mini_display::show_message(
                            "FACTORY RESET",
                            &format!("Reset in {}s...", remaining)
                        );
                    }
                }
                
                // Check for factory reset (≥10s)
                if !factory_reset_triggered && elapsed >= FACTORY_RESET_PRESS_MS {
                    info!("GPIO0 very long press ({}ms) — factory reset to cfg.toml defaults", elapsed);
                    crate::serial_display::show_system_message(
                        "FACTORY RESET",
                        "Erasing NVS...\nPlease wait..."
                    );
                    thread::sleep(Duration::from_millis(500)); // Give display time to update
                    crate::httpserver::factory_reset(); // never returns (no need to set flag)
                }
                // Check for DC OUT toggle (≥3s but <10s)
                else if !dcout_triggered && elapsed >= DCOUT_PRESS_MS {
                    dcout_triggered = true;
                    let current_state = gpio_pwm_state.get_gpio()[6]; // index 6 = GPIO12 = DC OUT
                    let new_state = !current_state;
                    gpio_pwm_state.set_gpio(6, new_state);
                    info!("GPIO0 medium press ({}ms) — toggling DC OUT (GPIO12): {} -> {}", 
                          elapsed, current_state, new_state);
                }
            }
        } else if btn_now && !btn_last {
            // ── Rising edge: button released ─────────────────────────────
            if !dcout_triggered && !factory_reset_triggered {
                if let Some(start) = press_start.take() {
                    let elapsed = start.elapsed().as_millis() as u64;
                    info!("GPIO0 short press ({}ms) — next display page", elapsed);
                    crate::serial_display::next_page();
                }
            }
            // Clear system message when button is released
            if display_updated {
                crate::serial_display::clear_system_message();
            }
            if mini_display_updated {
                crate::mini_display::clear_message();
            }
            press_start = None;
            dcout_triggered = false;
            factory_reset_triggered = false;
            display_updated = false;
            mini_display_updated = false;
        }

        btn_last = btn_now;
        thread::sleep(Duration::from_millis(50));
    }
}

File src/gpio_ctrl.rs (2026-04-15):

// GPIO / PWM control state shared between main loop and HTTP server
// GPIO 4-9  : digital output ON/OFF
// GPIO 10-11: PWM (LEDC) duty 0-100 %
// SPDX-License-Identifier: MIT

use std::sync::{Arc, Mutex};

/// GPIO index → physical pin number mapping.
/// Index 0-5 = GPIO4-9, index 6 = GPIO12.
pub const GPIO_PIN_MAP: [u8; 7] = [4, 5, 6, 7, 8, 9, 12];

/// Shared state: desired GPIO output values.
/// The main thread owns the hardware drivers; this struct carries only the
/// desired values that the HTTP handlers write and the main loop reads.
#[derive(Clone)]
pub struct GpioPwmState {
    /// ON/OFF for GPIO 4-9, 12.  Index 0 = GPIO4 … index 5 = GPIO9, index 6 = GPIO12.
    pub gpio_states: Arc<Mutex<[bool; 7]>>,
    /// PWM duty 0-100 % for GPIO 10-11.  Index 0 = GPIO10, index 1 = GPIO11.
    pub pwm_duties: Arc<Mutex<[u8; 2]>>,
}

impl GpioPwmState {
    pub fn new() -> Self {
        Self {
            gpio_states: Arc::new(Mutex::new([false; 7])),
            pwm_duties:  Arc::new(Mutex::new([0u8; 2])),
        }
    }

    /// Return a snapshot of pin states (thread-safe copy).
    pub fn get_gpio(&self) -> [bool; 7] {
        *self.gpio_states.lock().unwrap()
    }

    /// Return a snapshot of PWM duties (thread-safe copy).
    pub fn get_pwm(&self) -> [u8; 2] {
        *self.pwm_duties.lock().unwrap()
    }

    /// Set one GPIO output (index 0-5 → GPIO4-9, index 6 → GPIO12).
    pub fn set_gpio(&self, index: usize, value: bool) {
        if index < 7 {
            self.gpio_states.lock().unwrap()[index] = value;
        }
    }

    /// Set one PWM duty (index 0-1 → GPIO10-11, value 0-100).
    pub fn set_pwm(&self, index: usize, duty: u8) {
        if index < 2 {
            self.pwm_duties.lock().unwrap()[index] = duty.min(100);
        }
    }
}

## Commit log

2026-04-20 Fixed ssh-serial bridge received buffer
    [httpserver.rs, main.rs, serial_display.rs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]
2026-04-22 Fixed USB-CDC port select. Add NTP servers are configureble setting and PWM enable/disable setting
    [httpserver.rs, main.rs, usb_host.rs]
2026-04-23 Add power source detection
2026-04-23 Add support CDC devices
2026-04-23 Fixed GPIO pull-up mode
    [main.rs]
2026-04-24 Add configuration divider of ADC
2026-04-25 Add support CDC device for raspberry Pi
2026-05-01 Serial UART pins are pulled up
2026-05-09 Add HW schematic as KiCad
    [ssh-bridge-for-raspberrypi.kicad_pcb, ssh-bridge-for-raspberrypi.kicad_sch]
2026-05-11 Update ST7789V new 8pin foot print
    [bom.csv, designators.csv, positions.csv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]
2026-05-14 Fixed to reconnect WiFi AP when it is failed
    [main.rs]
2026-05-18 wifi: fix WPS credential capture when ap_cred_cnt > 0
    When WPS succeeds via the ap_cred_cnt > 0 path, esp_wifi_get_config()
    may not have the passphrase populated at the time the poll loop reads
    it, causing an empty password and a failed connection attempt.
    Fix by capturing SSID and passphrase directly from event_data->ap_cred[0]
    inside wps_event_handler (guarded by a null-check and ap_cred_cnt > 0).
    The credentials are stored in static buffers (WPS_SSID_BUF / WPS_PASS_BUF)
    and a new WPS_GOT_CREDS flag signals their availability to the poll loop
    via an Acquire/Release fence pair.
    The original esp_wifi_get_config() fallback is preserved for the
    ap_cred_cnt == 0 path where the driver connects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
2026-06-11 btn_ctrl: show factory reset countdown on mini display
    - Show overlay starting at 5s hold (1s earlier than serial display)
    - Update countdown every second until FACTORY_RESET_PRESS_MS
    - Clear overlay via mini_display::clear_message() on button release
    - Track mini_display_updated flag alongside existing display_updated
    [btn_ctrl.rs]
2026-06-11 main: show WPS connection status on mini display
    - Call mini_display::show_message() before starting WPS PBC
    - Call mini_display::clear_message() after WPS succeeds or fails
    - Refactor wifi_connect_wps result into local variable to allow cleanup
    [main.rs]
2026-06-11 ssh_bridge: drain wolfSSH channel buffer in a loop to fix large-paste echo
    wolfSSH_ChannelIdRead() returns at most sizeof(buf)=512 bytes per call.
    When a user pastes a long string, the entire payload arrives in one
    wolfSSH_worker() → WS_CHAN_RXD cycle. The previous code read only the
    first 512 bytes and forwarded them to the serial device; the remainder
    stayed in wolfSSH's internal channel buffer. On the next loop
    iteration wolfSSH_worker() finds nothing new on the non-blocking socket
    and returns WS_WANT_READ, so wolfSSH_ChannelIdRead() is never called
    for the leftover data. The device never receives the rest of the paste
    and never echoes it back, so the user sees a truncated or empty e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
    [ssh_bridge.c]
2026-06-11 docs: use board-specific cfg.toml copy instructions
2026-06-11 feat: add board-specific cfg templates
2026-07-05 ssh-serrial-bridge for raspberrypi
    [bom.csv, designators.csv, positions.csv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]
2026-07-05 Add mini-ssh-serial-bridge
    [BOM.csv, bom.csv, designators.csv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]
2026-07-07 Add SSH OTA update flow with safe reboot handling
    [partitions.csv]
2026-07-23 fix(usb_host): Handle large USB CDC writes by splitting into multiple bulk-OUT transfers
    Previously, usb_cdc_write_port() would silently discard any data beyond
    the first USB packet (typically 64 bytes). When a user pasted a longer
    command string via SSH or WebUI terminal, only the first ~64 bytes were
    sent to the serial device, leaving the shell waiting for the rest of the
    line. The missing input could only be recovered by Ctrl-C.
    This fix introduces usb_cdc_submit_chunk() to send one packet at a time,
    and refactors usb_cdc_write_port() to loop, submitting chunks and
    busy-waiting (bounded to 200ms) for each transfer to complete before
    submitting the next. The busy-wait is safe here because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
    [usb_host.rs]
2026-07-23 chore(setup): Improve setup_env.sh distro compatibility and espup robustness
    - Detect and use distro-specific libtinfo package (libtinfo5 vs libtinfo6)
    across Ubuntu/Debian versions for broader compatibility
    - Use versioned python*-venv package on Ubuntu, unversioned on Debian
    - Remove stale ~/.espup/esp-clang symlink before espup install/update
    to prevent 'File exists (os error 17)' errors on interrupted runs
    - Display detected distro/packages for debugging setup issues
2026-07-23 usb_host: fix WebUI terminal freeze during target boot
    - Increase WS ring buffer 64KB -> 256KB to absorb high-volume boot logs
    (~2-5 MB/s from systemd startup) without dropping data.
    - Reduce ws_sender_thread poll interval 5ms -> 1ms (200Hz -> 1000Hz) to
    drain buffers faster during bursts.
    - Add per-port overflow drop counters (AtomicU32; Xtensa lacks 64-bit
    atomics) with periodic warn! logging for diagnostics.
    [usb_host.rs]

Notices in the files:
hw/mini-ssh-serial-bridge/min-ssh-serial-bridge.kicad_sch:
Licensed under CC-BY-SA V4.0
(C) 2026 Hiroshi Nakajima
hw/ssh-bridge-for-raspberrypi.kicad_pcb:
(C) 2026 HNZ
